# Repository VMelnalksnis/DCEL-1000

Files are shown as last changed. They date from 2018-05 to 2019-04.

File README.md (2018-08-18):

# DCEL-1000

DCEL-1000 is a digital DC electronic load.
* Operates between 0 - 500 VDC, 4 μA<sup>1</sup> - 30A (~200 W maximum, depending on cooling solution)
* Two current ranges: 30 A (2 mA<sup>1</sup> resolution) and 50 mA (4 μA<sup>1</sup> resolution)
* Has dedicated voltage sense terminals
* Consists of two parallel MOSFETs with separate current sense and gate drive
* Controlled via opto-isolated 2.5 MHz SPI interface and control signals
* Requires +12 VDC, provides isolated +5 VDC (1 W)

<sup>1</sup> Theoretical resolution without oversampling assuming 2 LSB noise for current sense ADCs, most likely will change

## Table of contents

1. [About the project](#about-the-project)
1. [Project status](#project-status)
1. [Getting started](#getting-started)
	1. [Dependencies](#dependencies)
1. [License](#license)
1. [Authors](#authors)

# About the project

**[Back to top](#table-of-contents)**

# Project status

Currently working on finishing designing the hardware, both electrical and mechanical.

**[Back to top](#table-of-contents)**

# Getting Started

## Dependencies

* [My EAGLE libraries](https://github.com/VMelnalksnis/Eagle-Libraries)

**[Back to top](#table-of-contents)**

# License

Copyright (c) 2018 Valters Melnalksnis

This project is licensed under the MIT License - see [LICENSE.txt](LICENSE.txt) file for details.

**[Back to top](#table-of-contents)**

# Authors

* **[Valters Melnalksnis](https://github.com/vmelnalksnis)** - *Initial work*

**[Back to top](#table-of-contents)**

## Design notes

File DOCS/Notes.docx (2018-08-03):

The Intel E97378-001 CPU cooler I have has an average thermal resistance of 0.4045 (°C)/W [1] with the fan at maximum speed. Using a K6 Sil-Pad (with a thermal resistance of 0.58 (°C)/W ), at an ambient temperature of 25°C and a maximum junction temperature of 150°C , the maximum power a single MOSFET can dissipate ranges from 107.38W to 113.21W , and 85.9W to 90.57W at maximum junction temperature of 125°C .

Since the power capabilities of a single MOSFET are so low without an expensive cooling solution, the next best choice is to use multiple MOSFETs. When using multiple parallel MOSFETs, especially in linear mode, it is better to keep them at the same temperature to limit the possibility of thermal runaway or other failures due to differences between them. Currently the best way I see of doing that is using a copper busbar for the drain connections of the MOSFETs. This allows the usage of thermal grease, which offers the lowest thermal resistance between the case and heatsink ( <0.4(°C)/W , depending on the source). The busbar would then be mounted to an actively cooled heatsink with an electrically isolating thermal interface, most likely Sil-Pad. Although this increases the total thermal resistance between junction and heatsink, and thus ambient, it allows heat to escape the junction faster, which generally is the limiting factor, more so in pulse operation.

To sum up, use the CPU cooler pressure mounting the MOSFET between it and the PCB using a mounting bracket/backplate. Probably use the IXTK102N65X2, because it has a lowest R_(thJC) among DC SOA rated MOSFETs ( 0.12 (°C)/W versus 0.18(°C)/W on most others), resulting in 5% difference in maximum power using the Intel cooler, and increases with lower total thermal resistance. Furthermore, it has a DC SOA throughout its V_(DS) range of 650V , while the next best is 63V out of 250V . And it only costs 15.68€ . The only real downside is the current limit at low voltages – 20A@1V , 36A@2V .

When calculating maximum power at high currents, power dissipated in the sense resistor, PCB traces and wires should be accounted for; with 50A load on single MOSFET, the sense resistor will dissipate 5W, bypass MOSFETs will dissipate 4.5W, 10AWG wires will dissipate ~5W/m, in total adding about 15W per MOSFET.

- Simulate bypass driver on all 6 MOSFETs
- Figure out input protection
- Redesign the whole physical layout
- Find parts

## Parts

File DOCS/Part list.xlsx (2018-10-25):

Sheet: Used
Resistors
Value | Package | Count | Source | Link | Description | Price per | Total
0.01 | 6332 | 6 |  |  |  |  | €0.00
2 | 3216 | 6 | 610 3-10-2 |  |  |  | €0.00
16 | THT | 1 |  |  | RC snubber |  | €0.00
100 | 1608 | 7 | 610 3-13-3 |  |  |  | €0.00
350 | 1608 | 28 | 610 3-10-5 |  |  |  | €0.00
1000 | 1608 | 4 | 610 3-13-3 |  |  |  | €0.00
2150 | 2012 | 10 | 610 3-9-2 |  |  |  | €0.00
10000 | 1608 | 25 | 610 3-10-5 |  |  |  | €0.00
100000 | 1608 | 4 | 610 3-13-3 |  |  |  | €0.00
2000000 | 3216 | 5 | 610 3-25-2 |  |  |  | €0.00
Capacitors
Value | Package | Count | Source | Link | Description | Price per | Total
1.5e-11 | 1608 | 14 | 610 3-27-4 |  |  |  | €0.00
4.7e-10 | 1608 | 5 | 610 3-13-5 |  |  |  | €0.00
4.7e-10 | THT | 1 |  |  | 5V->5V coupling |  | €0.00
1e-08 | 2012 | 14 | 610 3-17-3 |  |  |  | €0.00
1e-07 | 1608 | 37 |  |  |  |  | €0.00
1.5e-07 | THT | 1 |  |  | RC snubber |  | €0.00
4.7e-07 | 1608 | 5 | 610 3-13-5 |  |  |  | €0.00
4.7e-06 | 3216 | 8 | 610 3-17-5 |  |  |  | €0.00
1e-05 | TANT-C | 2 | 610 3-14-4 |  |  |  | €0.00
4.7e-05 | TANT-D | 1 | 610 3-18-4 |  |  |  | €0.00
0.00022 | THT | 3 |  |  |  |  | €0.00
IC's
Value | Package | Count | Source | Link | Description | Price per | Total
AD420 | SO24W | 2 | 610 3-2-6 |  | 16-bit DAC |  | €0.00
AD620 | SO8 | 5 | 610 3-2-5 |  | Instrumentation amp |  | €0.00
HCPL-063N | SO8 | 7 | 610 3-2-6 |  | Dual opto-coupler |  | €0.00
L7805CV | TO220 | 2 | RTU |  | 5V Linear regulator |  | €0.00
LM50 | SOT23W | 2 | 610 3-14-1 |  | Temperature sensor |  | €0.00
LP2985-3.0 | SOT23-5L | 1 | 610 3-18-1 |  | LDO 3V regulator |  | €0.00
LT1014ISW | SO16W | 2 | RTU |  | Quad opamp |  | €0.00
LTC1865L | SO8 | 4 | 610 3-2-5 |  | 16-bit dual ADC |  | €0.00
MAX743WE | SO16W | 1 | 610 3-2-6 |  | 5V to +/-15V regulator |  | €0.00
Discrete semiconductors
Value | Package | Count | Source | Link | Description | Price per | Total
1N5817-B | DO41-7.6 | 2 | RTU |  |  |  | €0.00
BAS70-04 | SOT23 | 4 | 610 3-12-1 |  |  |  | €0.00
BC807-40 | SOT23 | 16 | 610 3-11-1 |  |  |  | €0.00
BC817-40 | SOT23 | 4 | 610 3-10-1 |  |  |  | €0.00
IXTK102N65X2 | TO264 | 2 | farnell | lv.farnell.com/ixys-semiconductor/ixtk102n65x2/mosfet-n-ch-650v-102a-to-264p/dp/2674784 |  | €12.88 | €25.76
SiRC10DP | SO8 | 4 | RTU |  |  |  | €0.00
Connectors
Value | Package | Count | Source | Link | Description | Price per | Total
Barrel Jack |  | 1 | Me |  |  |  | €0.00
Fan header | 4 pin | 2 |  |  |  |  | €0.00
Header pins |  | 1 | Me |  |  |  | €0.00
Screw terminals | 2/7.62 pitch | 2 | digikey | digikey.lv/product-detail/en/amphenol-anytek/T70243500000G/609-3954-ND/2261340 |  | €0.89 | €1.78
The rest
Value | Package | Count | Source | Link | Description | Price per | Total
100µ inductor |  | 2 | farnell | lv.farnell.com/coilcraft/mss1260-104mld/inductor-pwr-100uh-2-1a-20-8mhz/dp/2288438 |  | €1.22 | €2.44
Heatsink | LGA1155/755 | 2 | Me |  |  |  | €0.00
MOV |  | 4 |  |  |  |  | €0.00
RFMM-0505S | SIP7 | 1 | digikey | digikey.lv/products/en?keywords=RFMM-0505S | 5V->5V isolated supply | €1.45 | €1.45
Thermal interface |  |  |  |  |  |  | €0.00
Total: |  | 260 |  |  |  |  | €31.43

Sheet: Available
ADC |  | DAC |  | OpAmp |  | Vol.reg. |  | Temp. |  | Opto |  | Reference
Part | Location | Part | Location | Part | Location | Part | Location | Part | Location | Part | Location | Part
AD677 | 610-IC | AD420 | 610-IC | AD620 | 610-IC | 79L05 | 610-IC | LM20 | 610-IC | 4N37 | 610-IC | AD1582 | 610-IC
AD9235 | 610-IC | DAC08 | 610-IC | AD707 | 610-IC | LM2573 | 610-IC | LM50 | 610-IC | FOD817A | 610-IC | M109A | 610-IC
LC549 | 610-IC | LTC1453 | 610-IC | AD8065 | 610-IC | LM2671 | 610-IC | LM75A | 610-IC | HCNW2611 | 610-IC | LT1004CZ12 | 524-Mikro
LTC1865 | 610-IC | MAX518 | 610-IC | EL2044CSZ | 610-IC | LM2674 | 610-IC | LM45BIM3 | 524-Mikro | HCPL-061N | 610-IC
PCF8591 | 610-IC | PCF8591 | 610-IC | LF412C | 610-IC | LM317L | 610-IC | LM35D | 524-Mikro | HCPL-063N | 610-IC
DS11307 | 524-Mikro | LTC1663CS5 | 524-Mikro | LM7121 | 610-IC | LM5576 | 610-IC |  |  | PC355 | 610-IC
 |  |  |  | LM837 | 610-IC | LP2985AIM5-3.0 | 610-IC |  |  | SFH6156 | 610-IC
 |  |  |  | LMC660 | 610-IC | LP2985AIM5-3.1 | 610-IC |  |  | IL223AT | 524-Mikro
 |  |  |  | LMC662 | 610-IC | LT1761 | 610-IC
 |  |  |  | LT1014 | 610-IC | LT1964 | 610-IC
 |  |  |  | TL051C | 610-IC | LTC1261 | 610-IC
 |  |  |  | TLC27L4B | 610-IC | MAX743 | 610-IC
 |  |  |  | UA748CDP | 610-DIP | TL317 | 610-IC
 |  |  |  | LM837N | 610-DIP | TPS40055-EP | 610-IC
 |  |  |  | LM358N | 610-DIP | TPS767D301 | 610-IC
 |  |  |  | LF412CN | 610-DIP | XC6209F312MR | 610-IC
 |  |  |  | LF357 | 610-DIP | ICL7660CPA | 610-DIP
 |  |  |  | ICL7612BCPA | 610-DIP | TPS54616 | 524-Mikro
 |  |  |  | GL358 | 610-DIP | S-81250AG | 524-Mikro
 |  |  |  | AMP01FX | 610-DIP | LM79L05ACM | 524-Mikro
 |  |  |  | TS9241 | 524-Mikro | LM2576HVT-ADJ | 524-Mikro
 |  |  |  | TS902ID | 524-Mikro | LM1089CS-ADJ | 524-Mikro
 |  |  |  | TLC274CD | 524-Mikro | LM78M05CS | 524-Mikro
 |  |  |  | TLC271 | 524-Mikro | L4885CV | 524-Mikro
 |  |  |  | TLC074CN | 524-Mikro | 78L05 | 524-Mikro
 |  |  |  | TL084 | 524-Mikro
 |  |  |  | TL082CP | 524-Mikro
 |  |  |  | TL074 | 524-Mikro
 |  |  |  | TL064CD | 524-Mikro
 |  |  |  | TCA0372 | 524-Mikro
 |  |  |  | OPA77FP | 524-Mikro
 |  |  |  | OPA349 | 524-Mikro
 |  |  |  | OPA2137 | 524-Mikro
 |  |  |  | OP77E | 524-Mikro
 |  |  |  | LS204CN | 524-Mikro
 |  |  |  | LMC662AIN | 524-Mikro
 |  |  |  | LM258 | 524-Mikro
 |  |  |  | AD8532AR | 524-Mikro
 |  |  |  | AD811 | 524-Mikro
 |  |  |  | 27L4AC | 524-Mikro
 |  |  |  | 27L2C | 524-Mikro

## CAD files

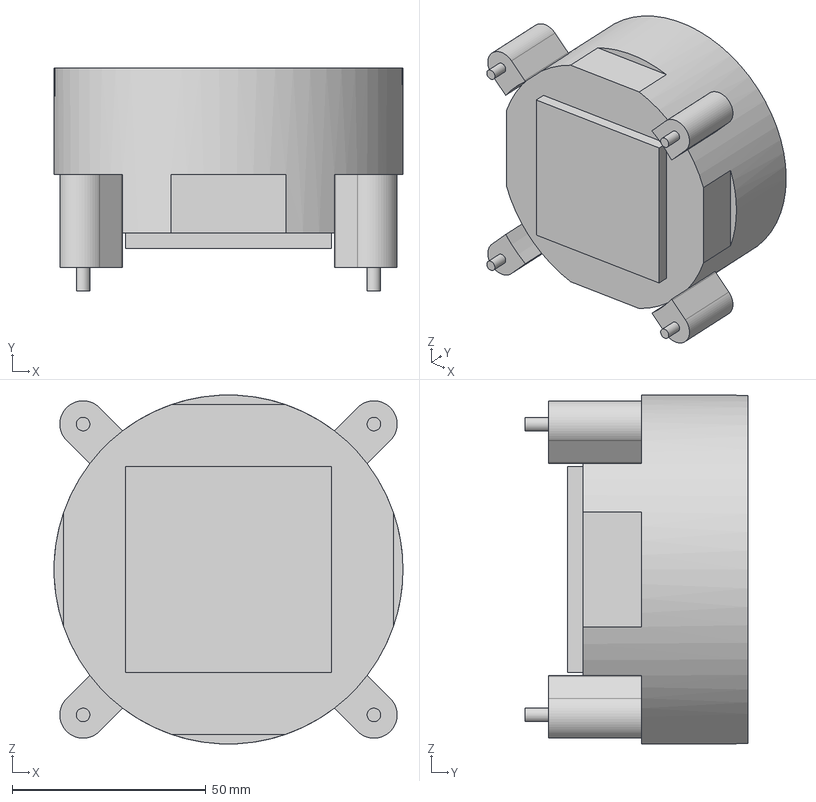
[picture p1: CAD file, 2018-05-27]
MODELS/Intel E97378-00.step
90.0 x 57.5 x 89.9 mm

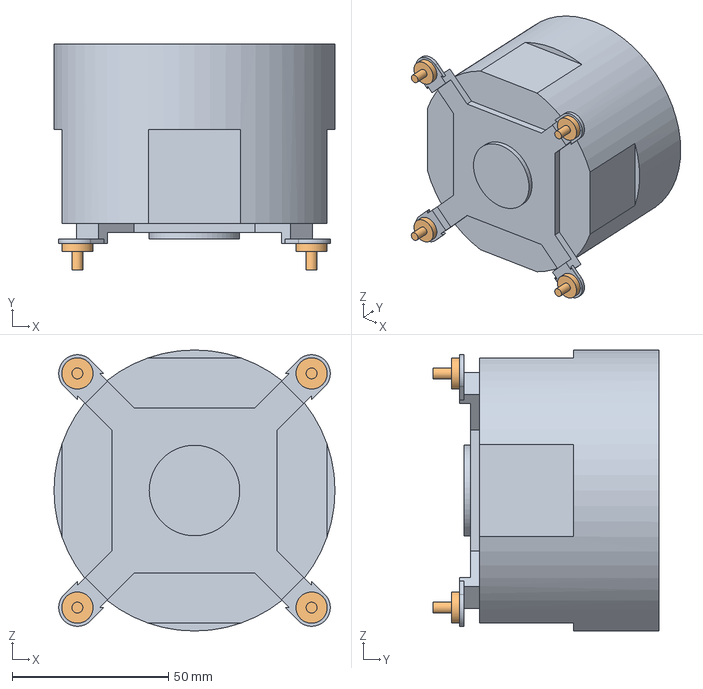
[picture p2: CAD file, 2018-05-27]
MODELS/Intel D95263-001.step
90.0 x 72.5 x 90.0 mm

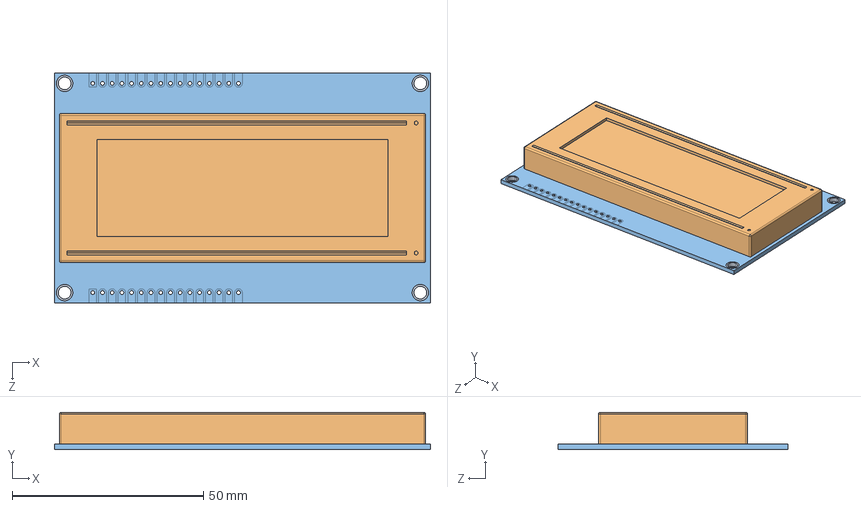
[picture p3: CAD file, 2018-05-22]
MODELS/20X4LCD JHD204A.STEP
98.3 x 9.76 x 60.0 mm

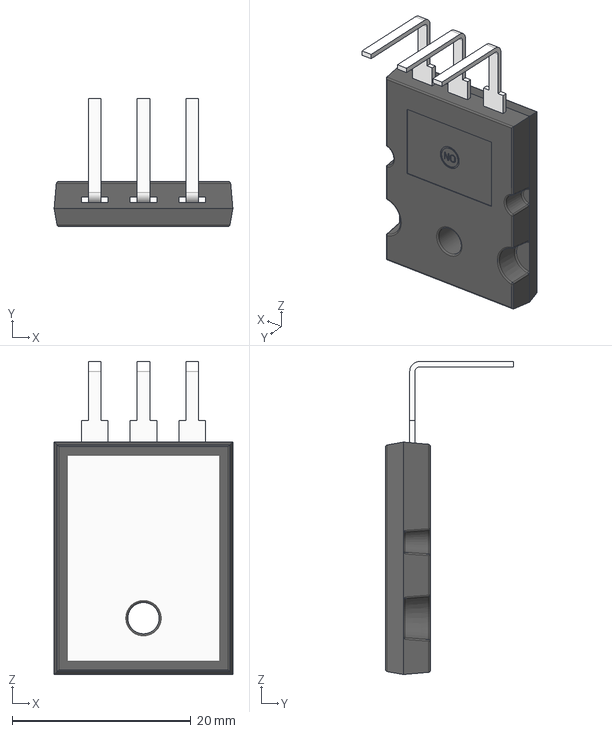
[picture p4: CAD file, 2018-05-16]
MODELS/TO-264-3-HM.stp
20.0 x 14.3 x 35.0 mm

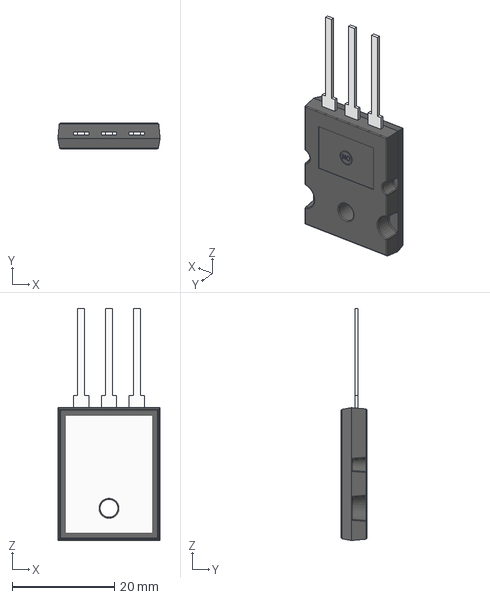
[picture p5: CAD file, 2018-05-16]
MODELS/TO-264-3-VM.stp
20.0 x 5.00 x 45.4 mm

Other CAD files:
MODELS/TO-264-3-HM.ipt
MODELS/TO-264-3-VM.ipt

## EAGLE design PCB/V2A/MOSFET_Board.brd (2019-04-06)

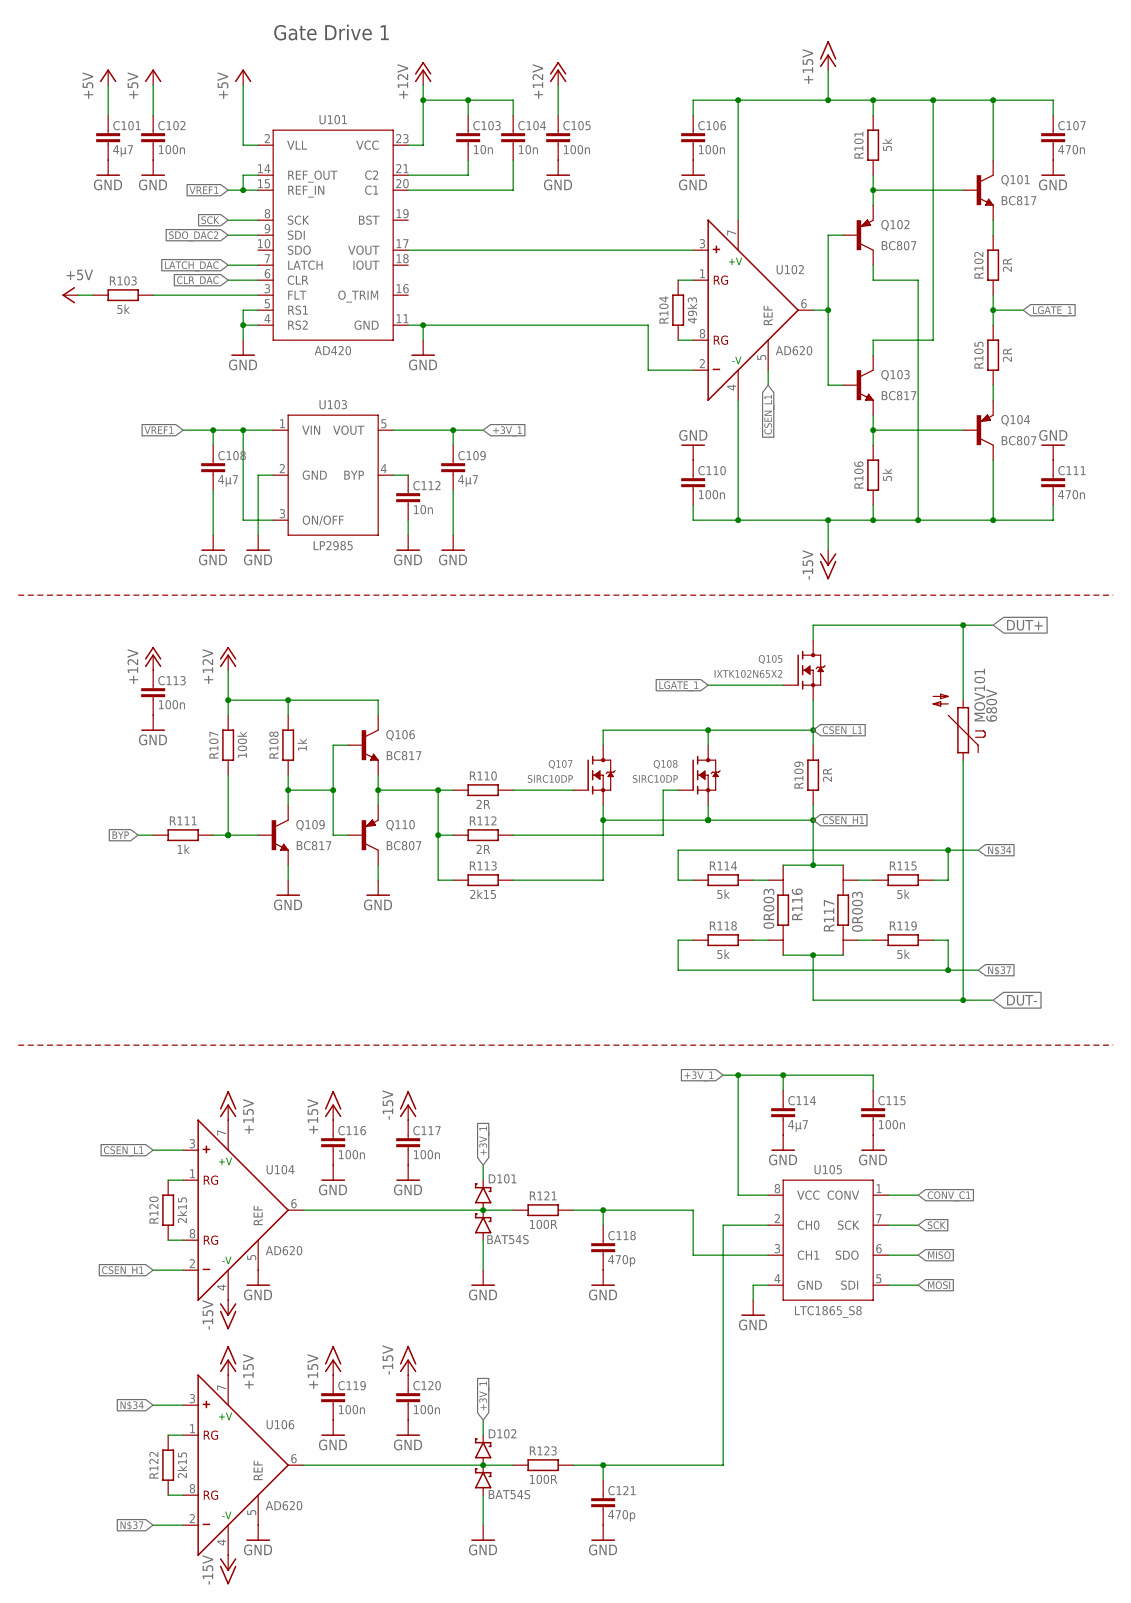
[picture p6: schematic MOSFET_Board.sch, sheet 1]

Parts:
C101, C108, C109, C114: 4µ7; CAPC3216X135
C102, C105, C106, C110, C113, C115, C116, C117, C119, C120: 100n; CAPC1508X45
C103, C104, C112: 10n; CAPC1508X45
C107, C111: 470n; CAPC1508X45
C118, C121: 470p; CAPC1508X45
D101, D102: BAT54S; SOT95P230X110-3
MOV101: 680V; S14K680
Q101, Q103, Q106, Q109: BC817; SOT95P240X110-3
Q102, Q104, Q110: BC807; SOT95P240X110-3
Q105: IXTK102N65X2; TO-264P-V
Q107, Q108: SIRC10DP; POWERPAK-SO-8
R101, R103, R106, R114, R115, R118, R119: 5k; RESC1608X70
R102, R105, R109, R110, R112: 2R; RESC3216X71
R104: 49k3; RESC1608X70
R107: 100k; RESC1608X70
R108, R111: 1k; RESC1608X70
R113, R120, R122: 2k15; RESC2012X65
R116, R117: 0R003; WSL3637_0.01
R121, R123: 100R; RESC1608X70
U101: AD420; SOIC127P1032X265-24
U102, U104, U106: AD620; SOIC127P599X175-8
U103: LP2985; SOT95P280X145-5
U105: LTC1865_S8; SOIC127P599X175-8

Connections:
+3V_1: C109.1, C114.1, C115.1, D101.2 (C2), D102.2 (C2), U103.5 (VOUT), U105.8 (VCC); also elsewhere on the board
+5V: C101.1, C102.1, R103.2, U101.2 (VLL); also elsewhere on the board
+12V: C103.1, C104.1, C105.1, C113.1, Q106.3 (C), R107.2, R108.2, U101.23 (VCC); also elsewhere on the board
+15V: C106.1, C107.1, C116.1, C119.1, Q101.3 (C), Q103.3 (C), R101.2, U102.7 (+V), U104.7 (+V), U106.7 (+V); also elsewhere on the board
-15V: C110.2, C111.2, C117.1, C120.1, Q102.3 (C), Q104.3 (C), R106.1, U102.4 (-V), U104.4 (-V), U106.4 (-V); also elsewhere on the board
BPY1G1: Q107.4 (G), R110.2
BYP: R111.1; also elsewhere on the board
BYP1: Q106.2 (E), Q110.2 (E), R110.1, R112.1, R113.1
BYP1G2: Q108.4 (G), R112.2
CLR_DAC: U101.6 (CLR); also elsewhere on the board
CONV_C1: U105.1 (CONV); also elsewhere on the board
CSEN_H1: Q107.1 (S), Q107.2 (S), Q107.3 (S), Q108.1 (S), Q108.2 (S), Q108.3 (S), R109.1, R113.2, R116.I1, R117.I2, U104.2 (-)
CSEN_L1: Q105.3 (S), Q107.5 (D), Q107.6 (D), Q107.7 (D), Q107.8 (D), Q108.5 (D), Q108.6 (D), Q108.7 (D), Q108.8 (D), R109.2, U102.5 (REF), U104.3 (+)
DUT+: MOV101.2, Q105.2 (D); also elsewhere on the board
DUT-: MOV101.1, R116.I2, R117.I1; also elsewhere on the board
GND: C101.2, C102.2, C105.2, C106.2, C107.2, C108.2, C109.2, C110.1, C111.1, C112.2, C113.2, C114.2, C115.2, C116.2, C117.2, C118.2, C119.2, C120.2, C121.2, D101.1 (A1), D102.1 (A1), Q109.2 (E), Q110.3 (C), U101.4 (RS2), U101.5 (RS1), U101.11 (GND), U102.2 (-), U103.2 (GND), U104.5 (REF), U105.4 (GND), U106.5 (REF); also elsewhere on the board
HIGHC1: C121.1, R123.2, U105.2 (CH0)
LATCH_DAC: U101.7 (LATCH); also elsewhere on the board
LGATE_1: Q105.1 (G), R102.1, R105.2
LOWC1: C118.1, R121.2, U105.3 (CH1)
MISO: U105.6 (SDO); also elsewhere on the board
MOSI: U105.5 (SDI); also elsewhere on the board
unnamed: Q101.1 (B), Q102.2 (E), R101.1
unnamed: R104.2, U102.1 (RG)
unnamed: C103.2, U101.21 (C2)
unnamed: C104.2, U101.20 (C1)
unnamed: Q106.1 (B), Q109.3 (C), Q110.1 (B), R108.1
unnamed: R104.1, U102.8 (RG)
unnamed: D102.3 (C1A2), R123.1, U106.6 (OUT)
unnamed: Q109.1 (B), R107.1, R111.2
unnamed: U101.17 (VOUT), U102.3 (+)
unnamed: C112.1, U103.4 (BYP)
unnamed: Q104.2 (E), R105.1
unnamed: Q101.2 (E), R102.2
unnamed: D101.3 (C1A2), R121.1, U104.6 (OUT)
unnamed: R115.2, R117.E2
unnamed: R114.1, R115.1, U106.3 (+)
unnamed: R116.E2, R118.1
unnamed: R118.2, R119.2, U106.2 (-)
unnamed: R117.E1, R119.1
unnamed: R114.2, R116.E1
unnamed: R103.1, U101.3 (FLT)
unnamed: Q102.1 (B), Q103.1 (B), U102.6 (OUT)
unnamed: Q103.2 (E), Q104.1 (B), R106.2
RG1_L3: R122.2, U106.1 (RG)
RG1_L4: R120.2, U104.1 (RG)
RG2_L3: R122.1, U106.8 (RG)
RG2_L4: R120.1, U104.8 (RG)
SCK: U101.8 (SCK), U105.7 (SCK); also elsewhere on the board
SDO_DAC2: U101.9 (SDI); also elsewhere on the board
VREF1: C108.1, U101.14 (REF_OUT), U101.15 (REF_IN), U103.1 (VIN), U103.3 (ON/OFF)

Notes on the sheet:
Gate Drive 1

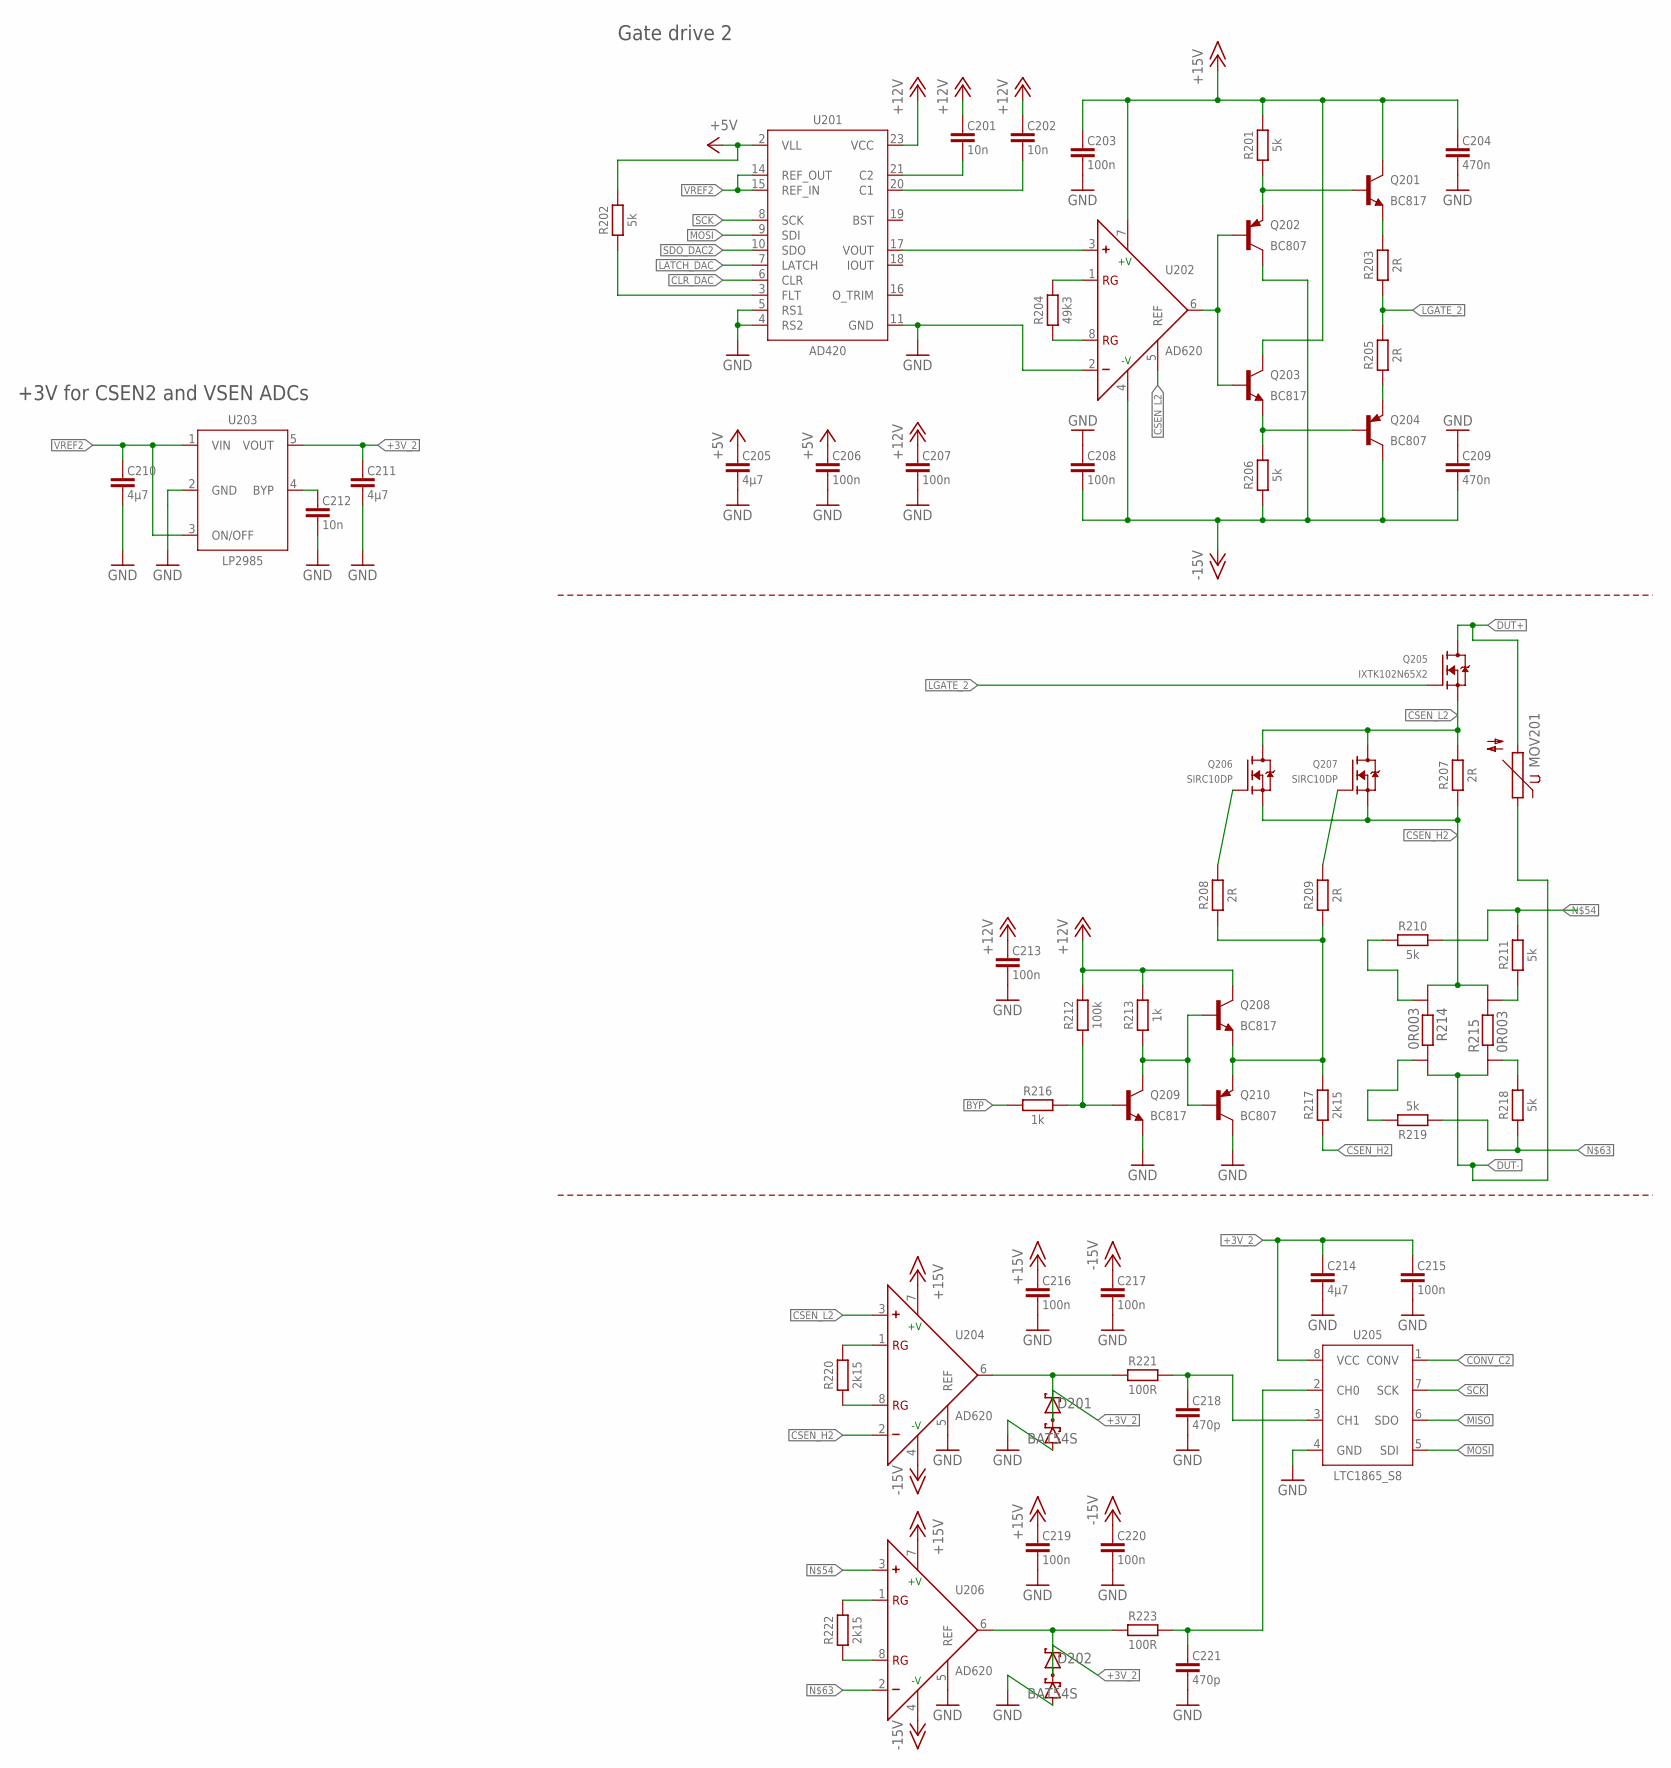
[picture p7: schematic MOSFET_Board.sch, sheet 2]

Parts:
C201, C202, C212: 10n; CAPC1508X45
C203, C206, C207, C208, C213, C215, C216, C217, C219, C220: 100n; CAPC1508X45
C204, C209: 470n; CAPC1508X45
C205, C210, C211, C214: 4µ7; CAPC3216X135
C218, C221: 470p; CAPC1508X45
D201, D202: BAT54S; SOT95P230X110-3
MOV201: MOV-14X7.4; S14K680
Q201, Q203, Q208, Q209: BC817; SOT95P240X110-3
Q202, Q204, Q210: BC807; SOT95P240X110-3
Q205: IXTK102N65X2; TO-264P-V
Q206, Q207: SIRC10DP; POWERPAK-SO-8
R201, R202, R206, R210, R211, R218, R219: 5k; RESC1608X70
R203, R205, R207, R208, R209: 2R; RESC3216X71
R204: 49k3; RESC1608X70
R212: 100k; RESC1608X70
R213, R216: 1k; RESC1608X70
R214, R215: 0R003; WSL3637_0.01
R217, R220, R222: 2k15; RESC2012X65
R221, R223: 100R; RESC1608X70
U201: AD420; SOIC127P1032X265-24
U202, U204, U206: AD620; SOIC127P599X175-8
U203: LP2985; SOT95P280X145-5
U205: LTC1865_S8; SOIC127P599X175-8

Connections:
+3V_2: C211.1, C214.1, C215.1, D201.2 (C2), D202.2 (C2), U203.5 (VOUT), U205.8 (VCC)
+5V: C205.1, C206.1, R202.2, U201.2 (VLL); also elsewhere on the board
+12V: C201.1, C202.1, C207.1, C213.1, Q208.3 (C), R212.2, R213.2, U201.23 (VCC); also elsewhere on the board
+15V: C203.1, C204.1, C216.1, C219.1, Q201.3 (C), Q203.3 (C), R201.2, U202.7 (+V), U204.7 (+V), U206.7 (+V); also elsewhere on the board
-15V: C208.2, C209.2, C217.1, C220.1, Q202.3 (C), Q204.3 (C), R206.1, U202.4 (-V), U204.4 (-V), U206.4 (-V); also elsewhere on the board
BYP: R216.1; also elsewhere on the board
BYP2: Q208.2 (E), Q210.2 (E), R208.1, R209.1, R217.2
BYP2G1: Q206.4 (G), R208.2
BYP2G2: Q207.4 (G), R209.2
CLR_DAC: U201.6 (CLR); also elsewhere on the board
CONV_C2: U205.1 (CONV); also elsewhere on the board
CSEN_H2: Q206.1 (S), Q206.2 (S), Q206.3 (S), Q207.1 (S), Q207.2 (S), Q207.3 (S), R207.1, R214.I1, R215.I2, R217.1, U204.2 (-)
CSEN_L2: Q205.3 (S), Q206.5 (D), Q206.6 (D), Q206.7 (D), Q206.8 (D), Q207.5 (D), Q207.6 (D), Q207.7 (D), Q207.8 (D), R207.2, U202.5 (REF), U204.3 (+)
DUT+: MOV201.2, Q205.2 (D); also elsewhere on the board
DUT-: MOV201.1, R214.I2, R215.I1; also elsewhere on the board
GND: C203.2, C204.2, C205.2, C206.2, C207.2, C208.1, C209.1, C210.2, C211.2, C212.2, C213.2, C214.2, C215.2, C216.2, C217.2, C218.2, C219.2, C220.2, C221.2, D201.1 (A1), D202.1 (A1), Q209.2 (E), Q210.3 (C), U201.4 (RS2), U201.5 (RS1), U201.11 (GND), U202.2 (-), U203.2 (GND), U204.5 (REF), U205.4 (GND), U206.5 (REF); also elsewhere on the board
HIGHC2: C221.1, R223.2, U205.2 (CH0)
LATCH_DAC: U201.7 (LATCH); also elsewhere on the board
LGATE_2: Q205.1 (G), R203.1, R205.2
LOWC2: C218.1, R221.2, U205.3 (CH1)
MISO: U205.6 (SDO); also elsewhere on the board
MOSI: U201.9 (SDI), U205.5 (SDI); also elsewhere on the board
unnamed: Q201.1 (B), Q202.2 (E), R201.1
unnamed: Q204.2 (E), R205.1
unnamed: Q201.2 (E), R203.2
unnamed: Q208.1 (B), Q209.3 (C), Q210.1 (B), R213.1
unnamed: Q209.1 (B), R212.1, R216.2
unnamed: R210.1, R214.E1
unnamed: C201.2, U201.21 (C2)
unnamed: C202.2, U201.20 (C1)
unnamed: Q202.1 (B), Q203.1 (B), U202.6 (OUT)
unnamed: Q203.2 (E), Q204.1 (B), R206.2
unnamed: R202.1, U201.3 (FLT)
unnamed: R211.1, R215.E2
unnamed: R204.2, U202.1 (RG)
unnamed: R204.1, U202.8 (RG)
unnamed: U201.17 (VOUT), U202.3 (+)
unnamed: R215.E1, R218.2
unnamed: R214.E2, R219.2
unnamed: R210.2, R211.2, U206.3 (+)
unnamed: D202.3 (C1A2), R223.1, U206.6 (OUT)
unnamed: D201.3 (C1A2), R221.1, U204.6 (OUT)
unnamed: C212.1, U203.4 (BYP)
unnamed: R218.1, R219.1, U206.2 (-)
RG1_L1: R222.2, U206.1 (RG)
RG1_L2: R220.2, U204.1 (RG)
RG2_L1: R222.1, U206.8 (RG)
RG2_L2: R220.1, U204.8 (RG)
SCK: U201.8 (SCK), U205.7 (SCK); also elsewhere on the board
SDO_DAC2: U201.10 (SDO); also elsewhere on the board
VREF2: C210.1, U201.14 (REF_OUT), U201.15 (REF_IN), U203.1 (VIN), U203.3 (ON/OFF)

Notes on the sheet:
Gate drive 2
+3V for CSEN2 and VSEN ADCs

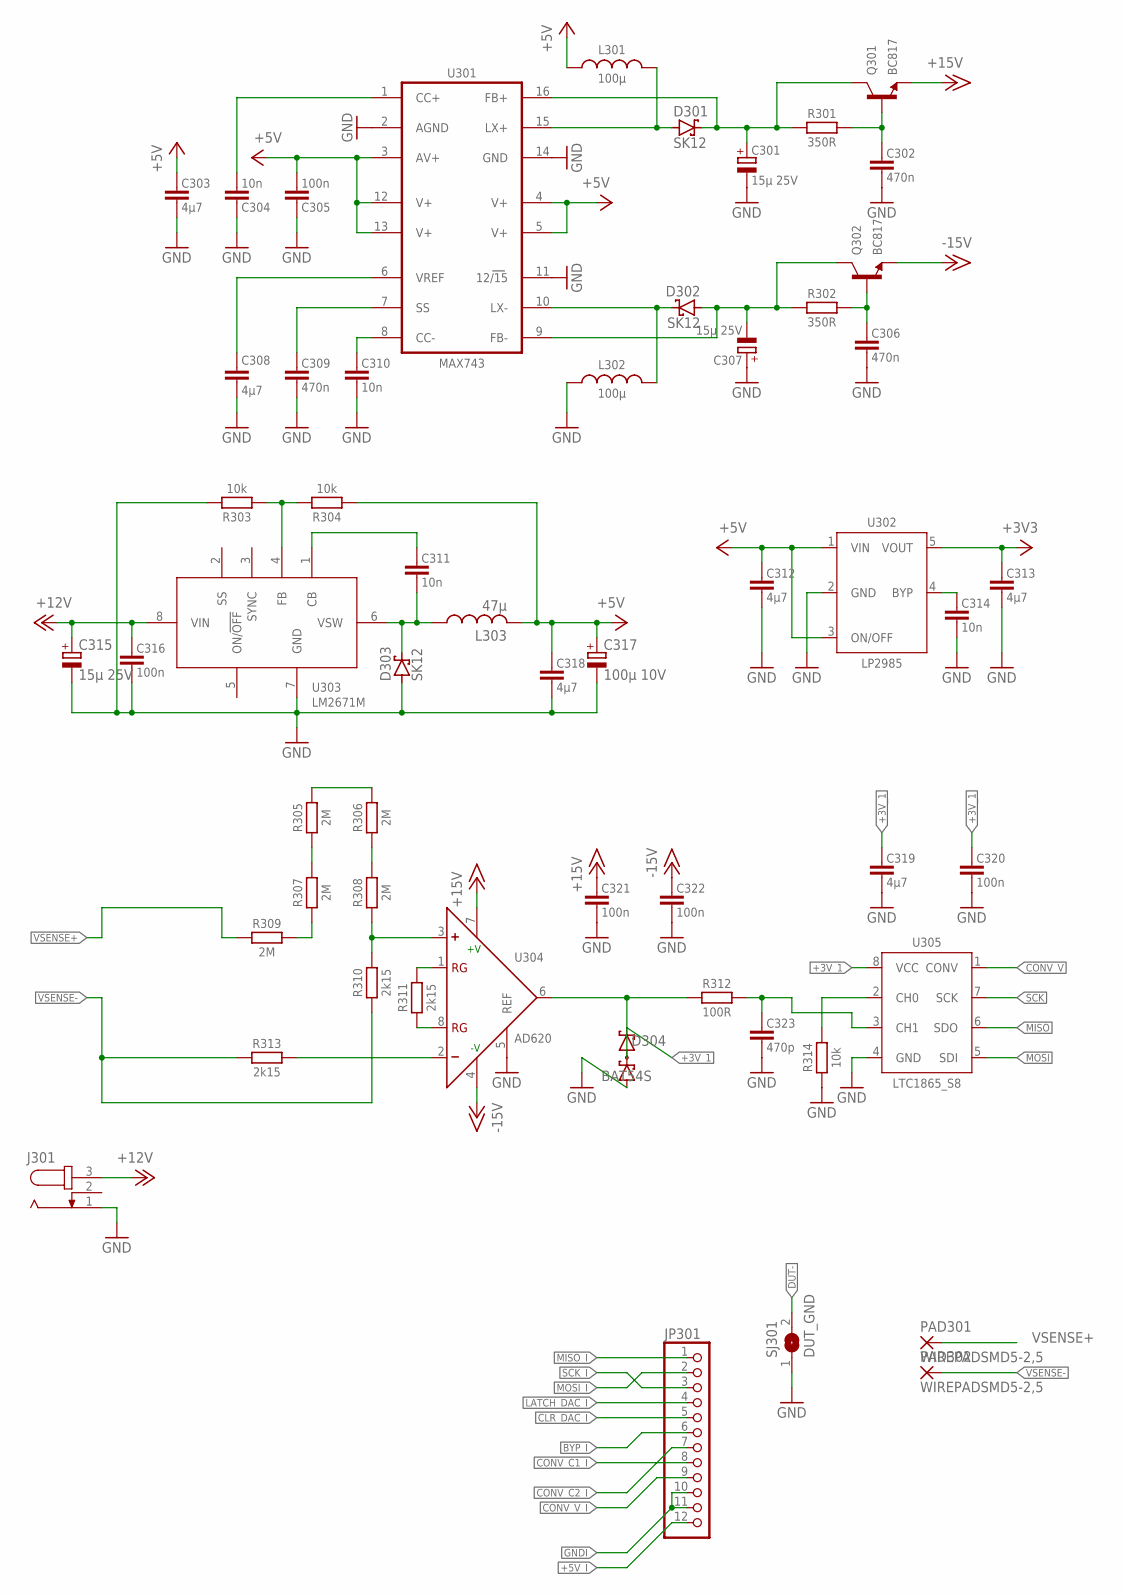
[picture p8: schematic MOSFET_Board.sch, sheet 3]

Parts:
C301, C307, C315: 15µ 25V; CAPCP7343X310
C302, C306, C309: 470n; CAPC1508X45
C303, C308, C312, C313, C318, C319: 4µ7; CAPC3216X135
C304, C310, C311, C314: 10n; CAPC1508X45
C305, C316, C320, C321, C322: 100n; CAPC1508X45
C317: 100µ 10V; CAPCP7343X310
C323: 470p; CAPC1508X45
D301, D302, D303: SK12; DIOM4336X262
D304: BAT54S; SOT95P230X110-3
J301: JACK-PLUG-2.5; SPC4078
JP301: PINHD-1X12; 1X12
L301, L302: 100µ; SRN5040
L303: 47µ; SRN5040
PAD301, PAD302: WIREPADSMD5-2,5; 5-2,5
Q301, Q302: BC817; SOT95P240X110-3
R301, R302: 350R; RESC1608X70
R303, R304, R314: 10k; RESC1608X70
R305, R306, R307, R308, R309: 2M; RESC3216X71
R310, R311, R313: 2k15; RESC2012X65
R312: 100R; RESC1608X70
SJ301: DUT_GND; SJW
U301: MAX743; SOIC127P1032X265-16
U302: LP2985; SOT95P280X145-5
U303: LM2671M; SOIC127P599X175-8
U304: AD620; SOIC127P599X175-8
U305: LTC1865_S8; SOIC127P599X175-8

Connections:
+3V3: C313.1, U302.5 (VOUT); also elsewhere on the board
+3V_1: C319.1, C320.1, D304.2 (C2), U305.8 (VCC); also elsewhere on the board
+5V: C303.1, C305.2, C312.1, C317.1 (+), C318.1, L301.1, L303.2, R304.1, U301.3 (AV+), U301.4 (V+), U301.5 (V+), U301.12 (V+), U301.13 (V+), U302.1 (VIN), U302.3 (ON/OFF); also elsewhere on the board
+5V_I: JP301.12; also elsewhere on the board
+12V: C315.1 (+), C316.1, J301.3, U303.8 (VIN); also elsewhere on the board
+15V: C321.1, Q301.2 (E), U304.7 (+V); also elsewhere on the board
-15V: C322.1, Q302.2 (E), U304.4 (-V); also elsewhere on the board
BYP_I: JP301.6; also elsewhere on the board
CLR_DAC_I: JP301.5; also elsewhere on the board
CONV_C1_I: JP301.8; also elsewhere on the board
CONV_C2_I: JP301.7; also elsewhere on the board
CONV_V: U305.1 (CONV); also elsewhere on the board
CONV_V_I: JP301.9; also elsewhere on the board
DUT-: SJ301.2; also elsewhere on the board
GND: C301.2 (-), C302.2, C303.2, C304.1, C305.1, C306.2, C307.1 (+), C308.2, C309.2, C310.2, C312.2, C313.2, C314.2, C315.2 (-), C316.2, C317.2 (-), C318.2, C319.2, C320.2, C321.2, C322.2, C323.2, D303.2 (A), D304.1 (A1), J301.1, L302.2, R303.2, R314.1, SJ301.1, U301.2 (AGND), U301.11 (12/15), U301.14 (GND), U302.2 (GND), U303.7 (GND), U304.5 (REF), U305.4 (GND); also elsewhere on the board
GNDI: JP301.10, JP301.11; also elsewhere on the board
LATCH_DAC_I: JP301.4; also elsewhere on the board
MISO: U305.6 (SDO); also elsewhere on the board
MISO_I: JP301.1; also elsewhere on the board
MOSI: U305.5 (SDI); also elsewhere on the board
MOSI_I: JP301.2; also elsewhere on the board
unnamed: C311.1, U303.1 (CB)
unnamed: C311.2, D303.1 (C), L303.1, U303.6 (VSW)
unnamed: R303.1, R304.2, U303.4 (FB)
unnamed: D304.3 (C1A2), R312.1, U304.6 (OUT)
unnamed: R306.1, R308.2
unnamed: R305.2, R306.2
unnamed: R305.1, R307.2
unnamed: R314.2, U305.2 (CH0)
unnamed: R308.1, R310.2, U304.3 (+)
unnamed: C323.1, R312.2, U305.3 (CH1)
unnamed: R307.1, R309.2
unnamed: R313.2, U304.2 (-)
unnamed: C310.1, U301.8 (CC-)
unnamed: C309.1, U301.7 (SS)
unnamed: C304.2, U301.1 (CC+)
unnamed: D301.2 (A), L301.2, U301.15 (LX+)
unnamed: C314.1, U302.4 (BYP)
unnamed: D302.1 (C), L302.1, U301.10 (LX-)
unnamed: C301.1 (+), D301.1 (C), Q301.3 (C), R301.1, U301.16 (FB+)
unnamed: C302.1, Q301.1 (B), R301.2
unnamed: C307.2 (-), D302.2 (A), Q302.3 (C), R302.1, U301.9 (FB-)
unnamed: C306.1, Q302.1 (B), R302.2
RG1_H6: R311.2, U304.1 (RG)
RG2_H6: R311.1, U304.8 (RG)
SCK: U305.7 (SCK); also elsewhere on the board
SCK_I: JP301.3; also elsewhere on the board
VREF_MAX743: C308.1, U301.6 (VREF)
VSENSE+: PAD301.1, R309.1
VSENSE-: PAD302.1, R310.1, R313.1

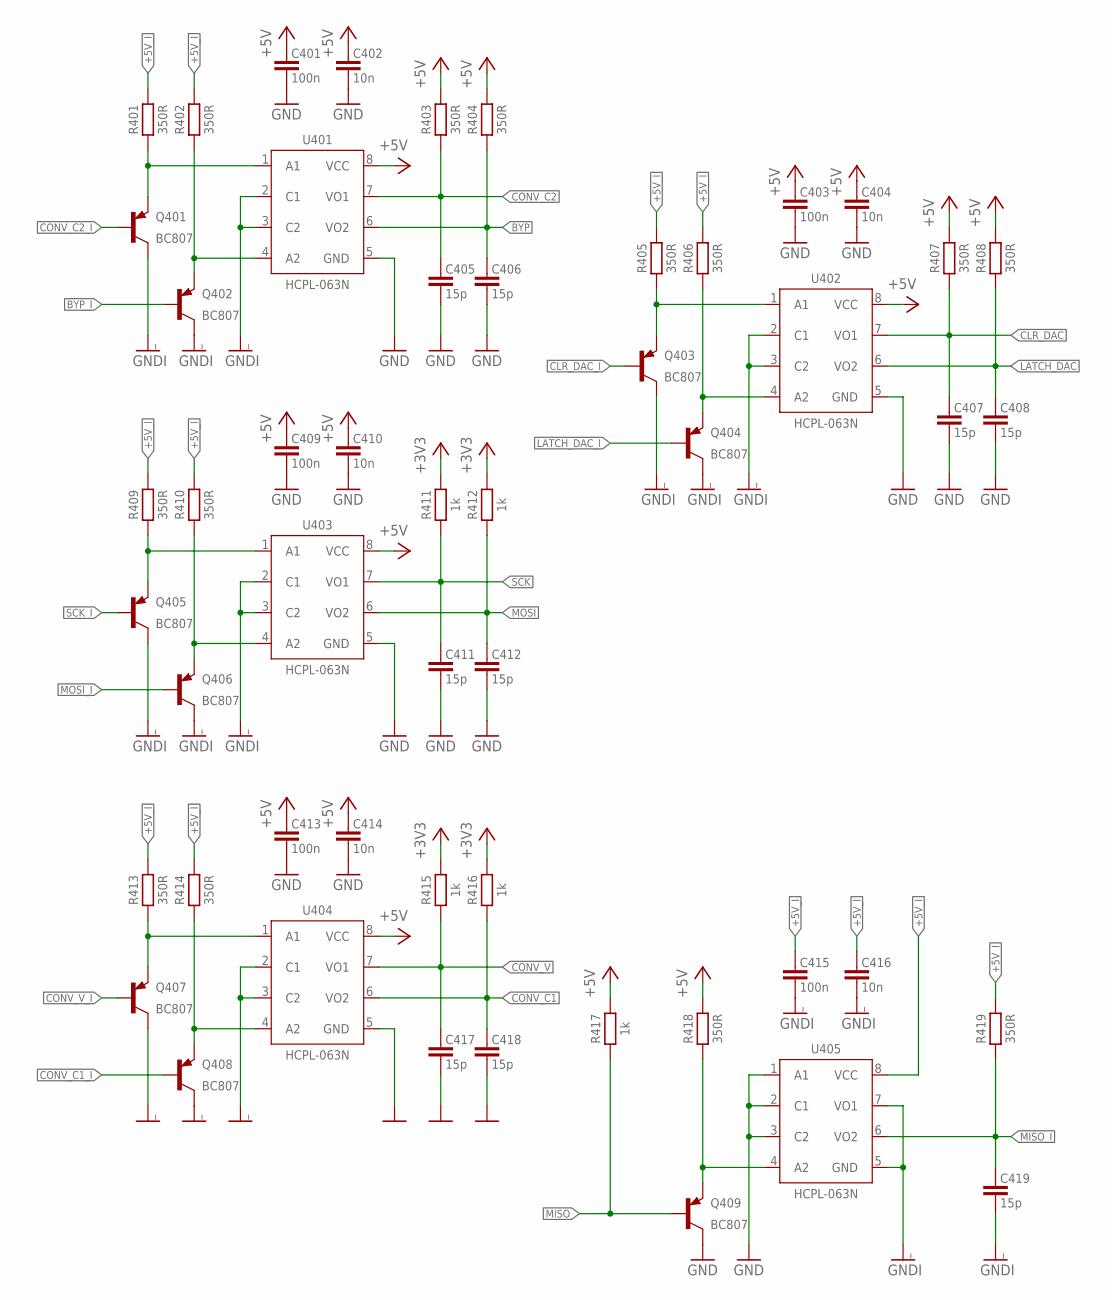
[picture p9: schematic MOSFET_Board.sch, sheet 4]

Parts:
C401, C403, C409, C413, C415: 100n; CAPC1508X45
C402, C404, C410, C414, C416: 10n; CAPC1508X45
C405, C406, C407, C408, C411, C412, C417, C418, C419: 15p; CAPC1508X45
Q401, Q402, Q403, Q404, Q405, Q406, Q407, Q408, Q409: BC807; SOT95P240X110-3
R401, R402, R403, R404, R405, R406, R407, R408, R409, R410, R413, R414, R418, R419: 350R; RESC1608X70
R411, R412, R415, R416, R417: 1k; RESC1608X70
U401, U402, U403, U404, U405: HCPL-063N; SOIC127P599X175-8

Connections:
+3V3: R411.2, R412.2, R415.2, R416.2; also elsewhere on the board
+5V: C401.1, C402.1, C403.1, C404.1, C409.1, C410.1, C413.1, C414.1, R403.2, R404.2, R407.2, R408.2, R417.2, R418.2, U401.8 (VCC), U402.8 (VCC), U403.8 (VCC), U404.8 (VCC); also elsewhere on the board
+5V_I: C415.1, C416.1, R401.2, R402.2, R405.2, R406.2, R409.2, R410.2, R413.2, R414.2, R419.2, U405.8 (VCC); also elsewhere on the board
BYP: C406.1, R404.1, U401.6 (VO2); also elsewhere on the board
BYP_I: Q402.1 (B); also elsewhere on the board
CLR_DAC: C407.1, R407.1, U402.7 (VO1); also elsewhere on the board
CLR_DAC_I: Q403.1 (B); also elsewhere on the board
CONV_C1: C418.1, R416.1, U404.6 (VO2); also elsewhere on the board
CONV_C1_I: Q408.1 (B); also elsewhere on the board
CONV_C2: C405.1, R403.1, U401.7 (VO1); also elsewhere on the board
CONV_C2_I: Q401.1 (B); also elsewhere on the board
CONV_V: C417.1, R415.1, U404.7 (VO1); also elsewhere on the board
CONV_V_I: Q407.1 (B); also elsewhere on the board
GND: C401.2, C402.2, C403.2, C404.2, C405.2, C406.2, C407.2, C408.2, C409.2, C410.2, C411.2, C412.2, C413.2, C414.2, C417.2, C418.2, Q409.3 (C), U401.5 (GND), U402.5 (GND), U403.5 (GND), U404.5 (GND), U405.1 (A1), U405.2 (C1), U405.3 (C2); also elsewhere on the board
GNDI: C415.2, C416.2, C419.2, Q401.3 (C), Q402.3 (C), Q403.3 (C), Q404.3 (C), Q405.3 (C), Q406.3 (C), Q407.3 (C), Q408.3 (C), U401.2 (C1), U401.3 (C2), U402.2 (C1), U402.3 (C2), U403.2 (C1), U403.3 (C2), U404.2 (C1), U404.3 (C2), U405.5 (GND), U405.7 (VO1); also elsewhere on the board
LATCH_DAC: C408.1, R408.1, U402.6 (VO2); also elsewhere on the board
LATCH_DAC_I: Q404.1 (B); also elsewhere on the board
MISO: Q409.1 (B), R417.1; also elsewhere on the board
MISO_I: C419.1, R419.1, U405.6 (VO2); also elsewhere on the board
MOSI: C412.1, R412.1, U403.6 (VO2); also elsewhere on the board
MOSI_I: Q406.1 (B); also elsewhere on the board
unnamed: Q409.2 (E), R418.1, U405.4 (A2)
unnamed: Q405.2 (E), R409.1, U403.1 (A1)
unnamed: Q406.2 (E), R410.1, U403.4 (A2)
unnamed: Q401.2 (E), R401.1, U401.1 (A1)
unnamed: Q402.2 (E), R402.1, U401.4 (A2)
unnamed: Q403.2 (E), R405.1, U402.1 (A1)
unnamed: Q404.2 (E), R406.1, U402.4 (A2)
unnamed: Q407.2 (E), R413.1, U404.1 (A1)
unnamed: Q408.2 (E), R414.1, U404.4 (A2)
SCK: C411.1, R411.1, U403.7 (VO1); also elsewhere on the board
SCK_I: Q405.1 (B); also elsewhere on the board

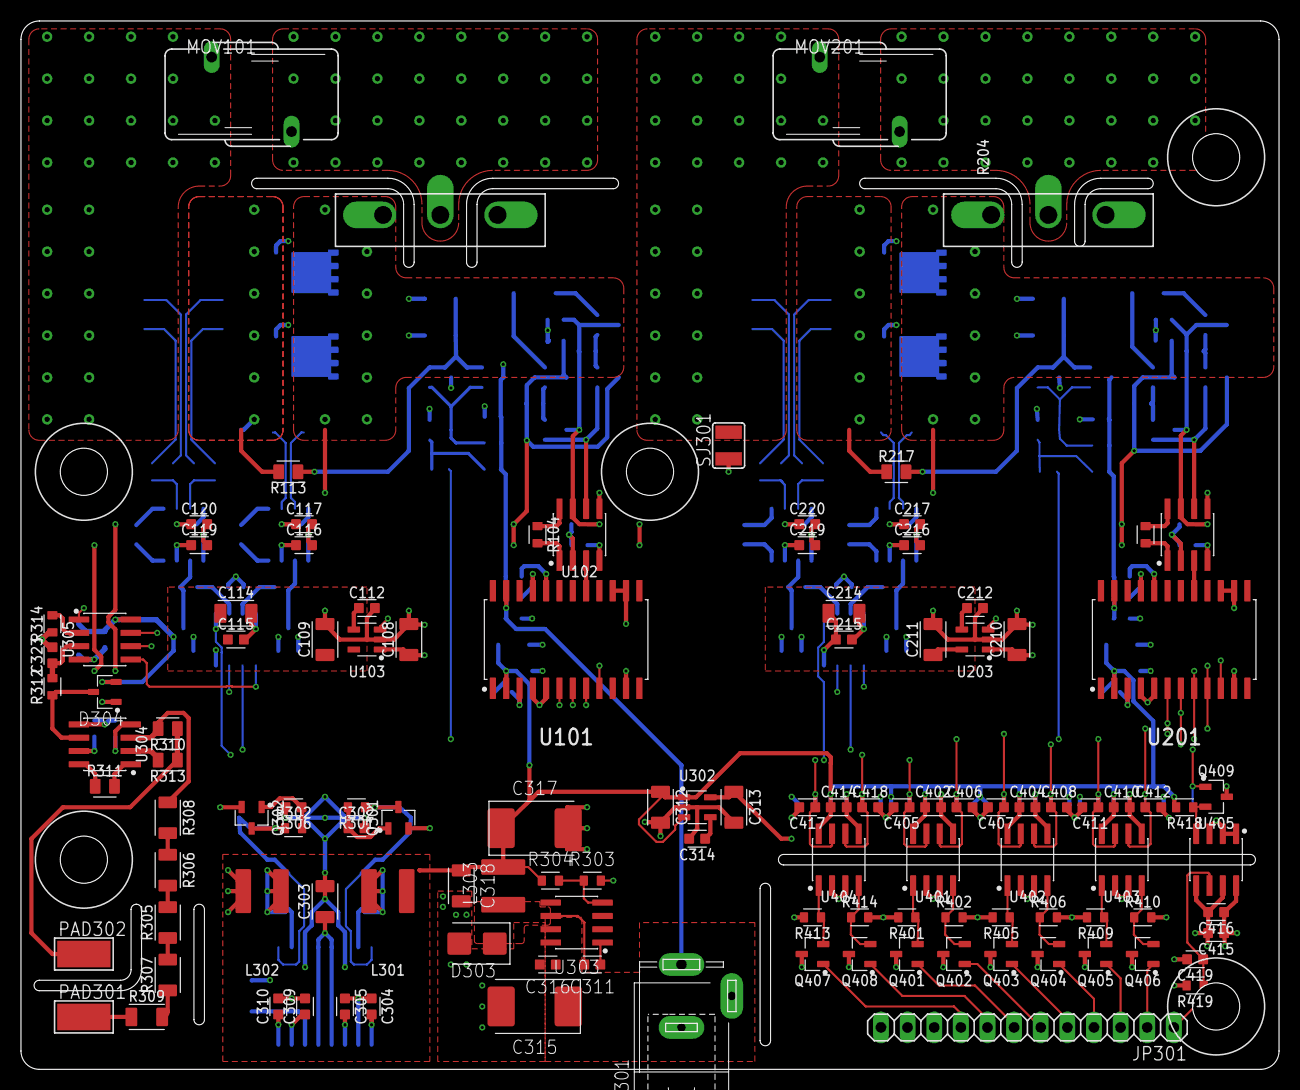
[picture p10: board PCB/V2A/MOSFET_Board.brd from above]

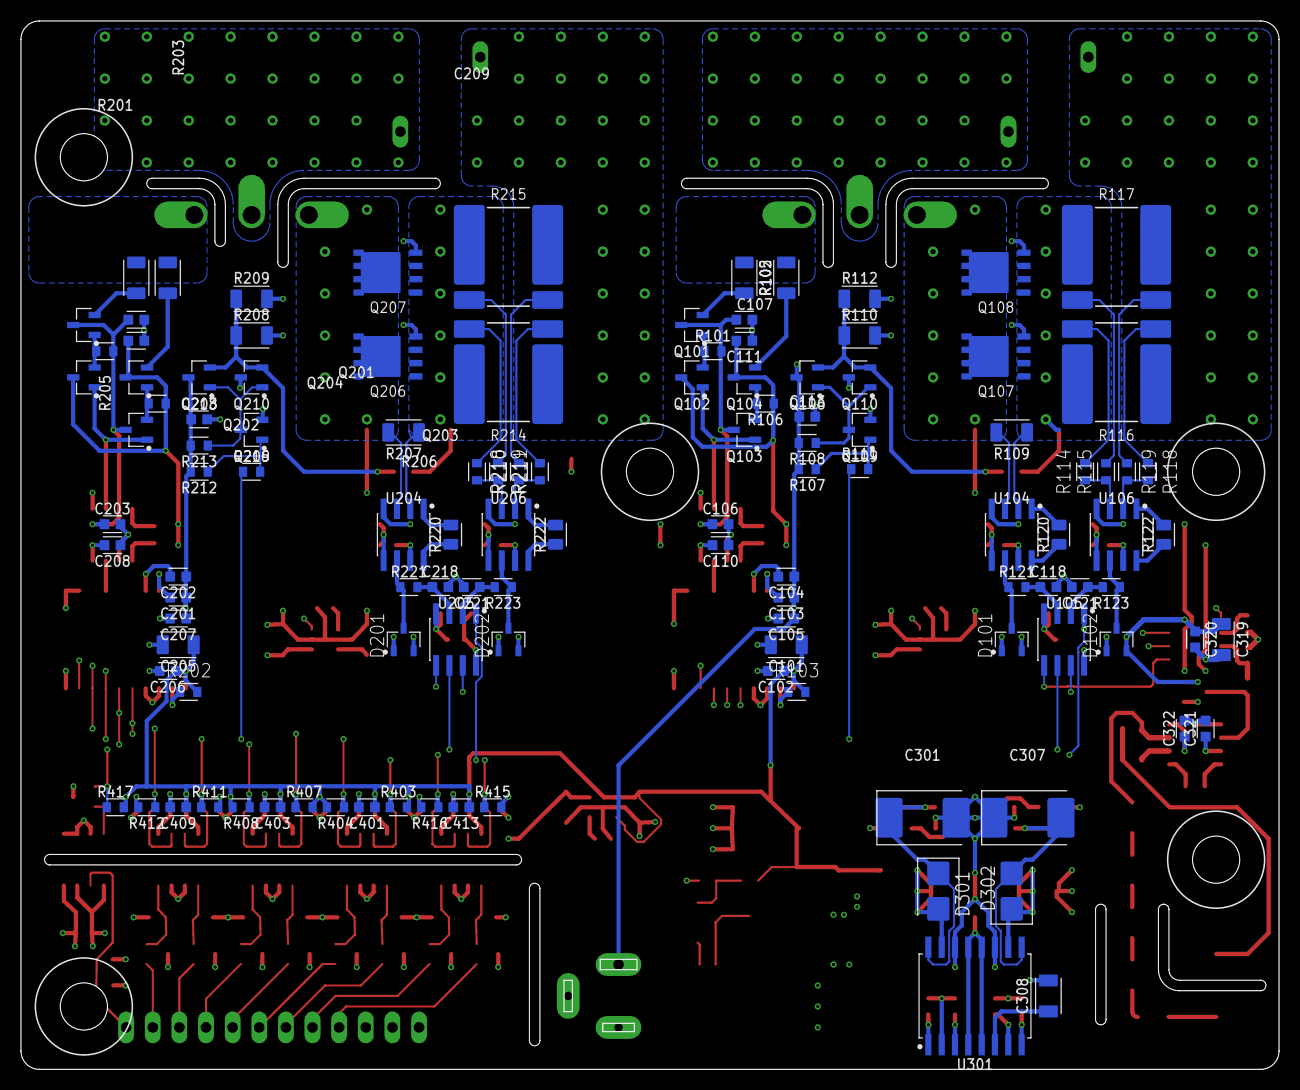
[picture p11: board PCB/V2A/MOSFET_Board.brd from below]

Board: 4 copper layers, 120.0 x 100.0 mm, 239 parts (117 on the bottom side), 137 nets.

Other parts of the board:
U$1, U$2, U$3, U$4, U$5: M4

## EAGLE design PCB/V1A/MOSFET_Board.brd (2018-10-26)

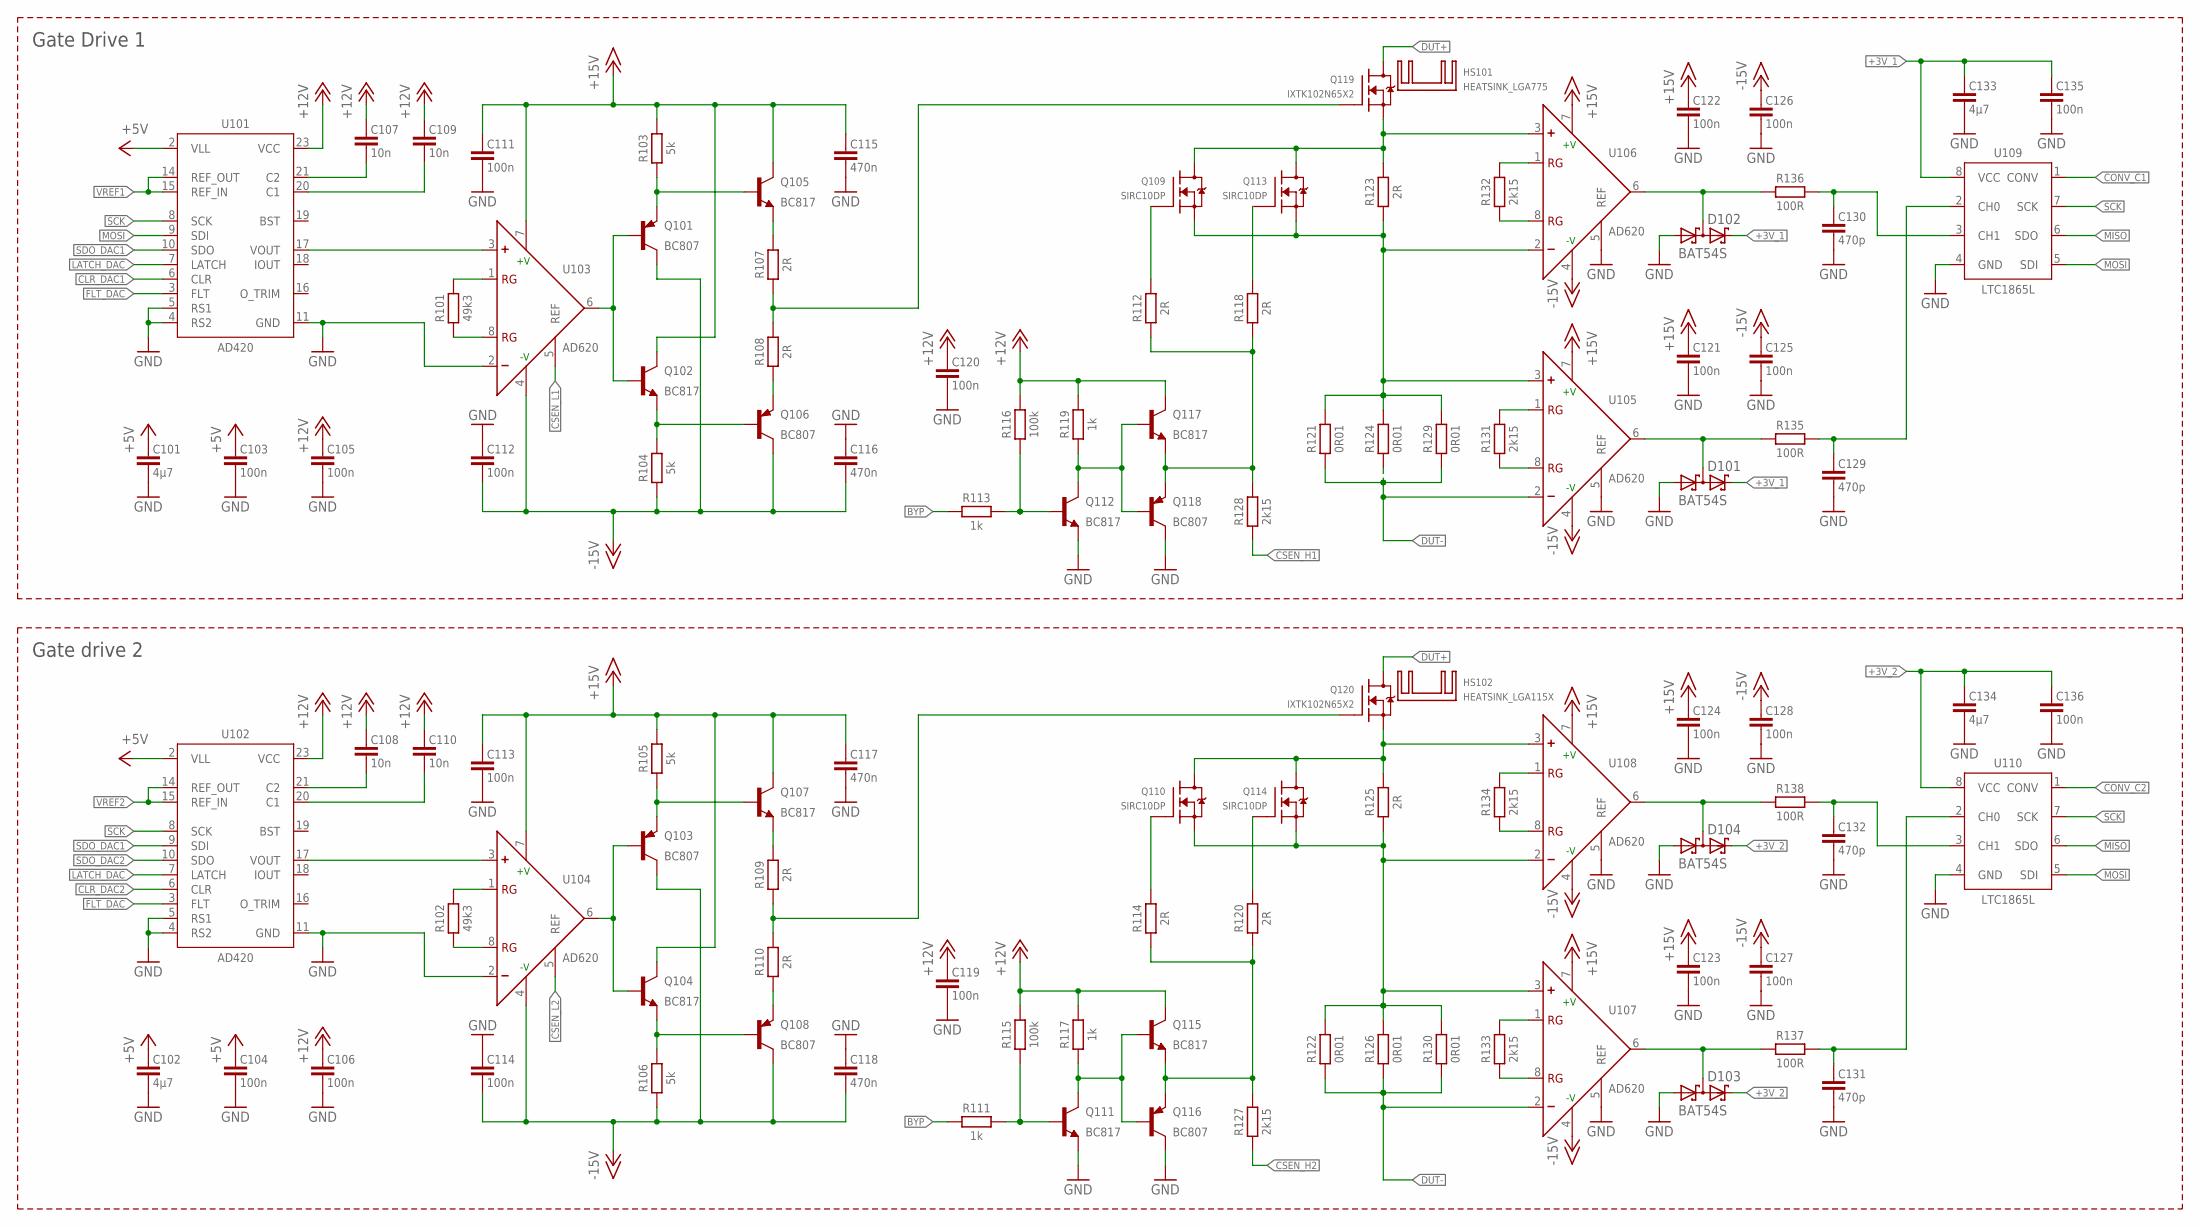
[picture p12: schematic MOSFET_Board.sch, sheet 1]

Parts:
C101, C102, C133, C134: 4µ7; CAPC3216
C103, C104, C105, C106, C111, C112, C113, C114, C119, C120, C121, C122, C123, C124, C125, C126, C127, C128, C135, C136: 100n; CAPC1608
C107, C108, C109, C110: 10n; CAPC2012
C115, C116, C117, C118: 470n; CAPC1608
C129, C130, C131, C132: 470p; CAPC1608
D101, D102, D103, D104: BAT54S; SOT23
HS101: HEATSINK_LGA775; D95263-001
HS102: HEATSINK_LGA115X; E97378-001
Q101, Q103, Q106, Q108, Q116, Q118: BC807; SOT23
Q102, Q104, Q105, Q107, Q111, Q112, Q115, Q117: BC817; SOT23
Q109, Q110, Q113, Q114: SIRC10DP; POWERPAK-SO-8
Q119, Q120: IXTK102N65X2; TO-264P-H-PADUP
R101, R102: 49k3; RESC1608
R103, R104, R105, R106: 5k; RESC1608
R107, R108, R109, R110, R112, R114, R118, R120, R123, R125: 2R; RESC3216
R111, R113, R117, R119: 1k; RESC1608
R115, R116: 100k; RESC1608
R121, R122, R124, R126, R129, R130: 0R01; RESC6332
R127, R128, R131, R132, R133, R134: 2k15; RESC2012
R135, R136, R137, R138: 100R; RESC1608
U101, U102: AD420; SO24W
U103, U104, U105, U106, U107, U108: AD620; SO8
U109, U110: LTC1865L; SO8

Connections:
+3V_1: C133.1, C135.1, D101.2 (C2), D102.2 (C2), U109.8 (VCC); also elsewhere on the board
+3V_2: C134.1, C136.1, D103.2 (C2), D104.2 (C2), U110.8 (VCC); also elsewhere on the board
+5V: C101.1, C102.1, C103.1, C104.1, U101.2 (VLL), U102.2 (VLL); also elsewhere on the board
+12V: C105.1, C106.1, C107.1, C108.1, C109.1, C110.1, C119.1, C120.1, Q115.3 (C), Q117.3 (C), R115.2, R116.2, R117.2, R119.2, U101.23 (VCC), U102.23 (VCC); also elsewhere on the board
+15V: C111.1, C113.1, C115.1, C117.1, C121.1, C122.1, C123.1, C124.1, Q102.3 (C), Q104.3 (C), Q105.3 (C), Q107.3 (C), R103.2, R105.2, U103.7 (+V), U104.7 (+V), U105.7 (+V), U106.7 (+V), U107.7 (+V), U108.7 (+V); also elsewhere on the board
-15V: C112.2, C114.2, C116.2, C118.2, C125.1, C126.1, C127.1, C128.1, Q101.3 (C), Q103.3 (C), Q106.3 (C), Q108.3 (C), R104.1, R106.1, U103.4 (-V), U104.4 (-V), U105.4 (-V), U106.4 (-V), U107.4 (-V), U108.4 (-V); also elsewhere on the board
BPY1G1: Q109.4 (G), R112.2
BYP: R111.1, R113.1; also elsewhere on the board
BYP1: Q117.2 (E), Q118.2 (E), R112.1, R118.1, R128.1
BYP1G2: Q113.4 (G), R118.2
BYP2: Q115.2 (E), Q116.2 (E), R114.1, R120.1, R127.2
BYP2G1: Q110.4 (G), R114.2
BYP2G2: Q114.4 (G), R120.2
CLR_DAC1: U101.6 (CLR); also elsewhere on the board
CLR_DAC2: U102.6 (CLR); also elsewhere on the board
CONV_C1: U109.1 (CONV); also elsewhere on the board
CONV_C2: U110.1 (CONV); also elsewhere on the board
CSEN_H1: Q109.1 (S), Q109.2 (S), Q109.3 (S), Q113.1 (S), Q113.2 (S), Q113.3 (S), R121.2, R123.1, R124.2, R128.2, R129.2, U105.3 (+), U106.2 (-)
CSEN_H2: Q110.1 (S), Q110.2 (S), Q110.3 (S), Q114.1 (S), Q114.2 (S), Q114.3 (S), R122.2, R125.1, R126.2, R127.1, R130.2, U107.3 (+), U108.2 (-)
CSEN_L1: Q109.5 (D), Q109.6 (D), Q109.7 (D), Q109.8 (D), Q113.5 (D), Q113.6 (D), Q113.7 (D), Q113.8 (D), Q119.1 (S), R123.2, U103.5 (REF), U106.3 (+)
CSEN_L2: Q110.5 (D), Q110.6 (D), Q110.7 (D), Q110.8 (D), Q114.5 (D), Q114.6 (D), Q114.7 (D), Q114.8 (D), Q120.1 (S), R125.2, U104.5 (REF), U108.3 (+)
DUT+: Q119.2 (D), Q120.2 (D); also elsewhere on the board
DUT-: R121.1, R122.1, R124.1, R126.1, R129.1, R130.1, U105.2 (-), U107.2 (-); also elsewhere on the board
FLT_DAC: U101.3 (FLT), U102.3 (FLT); also elsewhere on the board
GND: C101.2, C102.2, C103.2, C104.2, C105.2, C106.2, C111.2, C112.1, C113.2, C114.1, C115.2, C116.1, C117.2, C118.1, C119.2, C120.2, C121.2, C122.2, C123.2, C124.2, C125.2, C126.2, C127.2, C128.2, C129.2, C130.2, C131.2, C132.2, C133.2, C134.2, C135.2, C136.2, D101.1 (A1), D102.1 (A1), D103.1 (A1), D104.1 (A1), Q111.2 (E), Q112.2 (E), Q116.3 (C), Q118.3 (C), U101.4 (RS2), U101.5 (RS1), U101.11 (GND), U102.4 (RS2), U102.5 (RS1), U102.11 (GND), U103.2 (-), U104.2 (-), U105.5 (REF), U106.5 (REF), U107.5 (REF), U108.5 (REF), U109.4 (GND), U110.4 (GND); also elsewhere on the board
HIGHC1: C129.1, R135.2, U109.2 (CH0)
HIGHC2: C131.1, R137.2, U110.2 (CH0)
LATCH_DAC: U101.7 (LATCH), U102.7 (LATCH); also elsewhere on the board
LGATE_1: Q119.3 (G), R107.1, R108.2
LGATE_2: Q120.3 (G), R109.1, R110.2
LOWC1: C130.1, R136.2, U109.3 (CH1)
LOWC2: C132.1, R138.2, U110.3 (CH1)
MISO: U109.6 (SDO), U110.6 (SDO); also elsewhere on the board
MOSI: U101.9 (SDI), U109.5 (SDI), U110.5 (SDI); also elsewhere on the board
unnamed: Q101.2 (E), Q105.1 (B), R103.1
unnamed: R101.2, U103.1 (RG)
unnamed: C107.2, U101.21 (C2)
unnamed: C109.2, U101.20 (C1)
unnamed: Q112.3 (C), Q117.1 (B), Q118.1 (B), R119.1
unnamed: R101.1, U103.8 (RG)
unnamed: D101.3 (C1A2), R135.1, U105.6 (OUT)
unnamed: Q112.1 (B), R113.2, R116.1
unnamed: U101.17 (VOUT), U103.3 (+)
unnamed: Q106.2 (E), R108.1
unnamed: Q103.2 (E), Q107.1 (B), R105.1
unnamed: Q105.2 (E), R107.2
unnamed: Q108.2 (E), R110.1
unnamed: Q107.2 (E), R109.2
unnamed: D102.3 (C1A2), R136.1, U106.6 (OUT)
unnamed: Q111.3 (C), Q115.1 (B), Q116.1 (B), R117.1
unnamed: Q111.1 (B), R111.2, R115.1
unnamed: C108.2, U102.21 (C2)
unnamed: C110.2, U102.20 (C1)
unnamed: Q103.1 (B), Q104.1 (B), U104.6 (OUT)
unnamed: Q104.2 (E), Q108.1 (B), R106.2
unnamed: R102.2, U104.1 (RG)
unnamed: R102.1, U104.8 (RG)
unnamed: U102.17 (VOUT), U104.3 (+)
unnamed: D103.3 (C1A2), R137.1, U107.6 (OUT)
unnamed: D104.3 (C1A2), R138.1, U108.6 (OUT)
unnamed: Q101.1 (B), Q102.1 (B), U103.6 (OUT)
unnamed: Q102.2 (E), Q106.1 (B), R104.2
RG1_L1: R133.2, U107.1 (RG)
RG1_L2: R134.2, U108.1 (RG)
RG1_L3: R131.2, U105.1 (RG)
RG1_L4: R132.2, U106.1 (RG)
RG2_L1: R133.1, U107.8 (RG)
RG2_L2: R134.1, U108.8 (RG)
RG2_L3: R131.1, U105.8 (RG)
RG2_L4: R132.1, U106.8 (RG)
SCK: U101.8 (SCK), U102.8 (SCK), U109.7 (SCK), U110.7 (SCK); also elsewhere on the board
SDO_DAC1: U101.10 (SDO), U102.9 (SDI)
SDO_DAC2: U102.10 (SDO)
VREF1: U101.14 (REF_OUT), U101.15 (REF_IN); also elsewhere on the board
VREF2: U102.14 (REF_OUT), U102.15 (REF_IN); also elsewhere on the board

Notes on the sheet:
Gate Drive 1
Gate drive 2

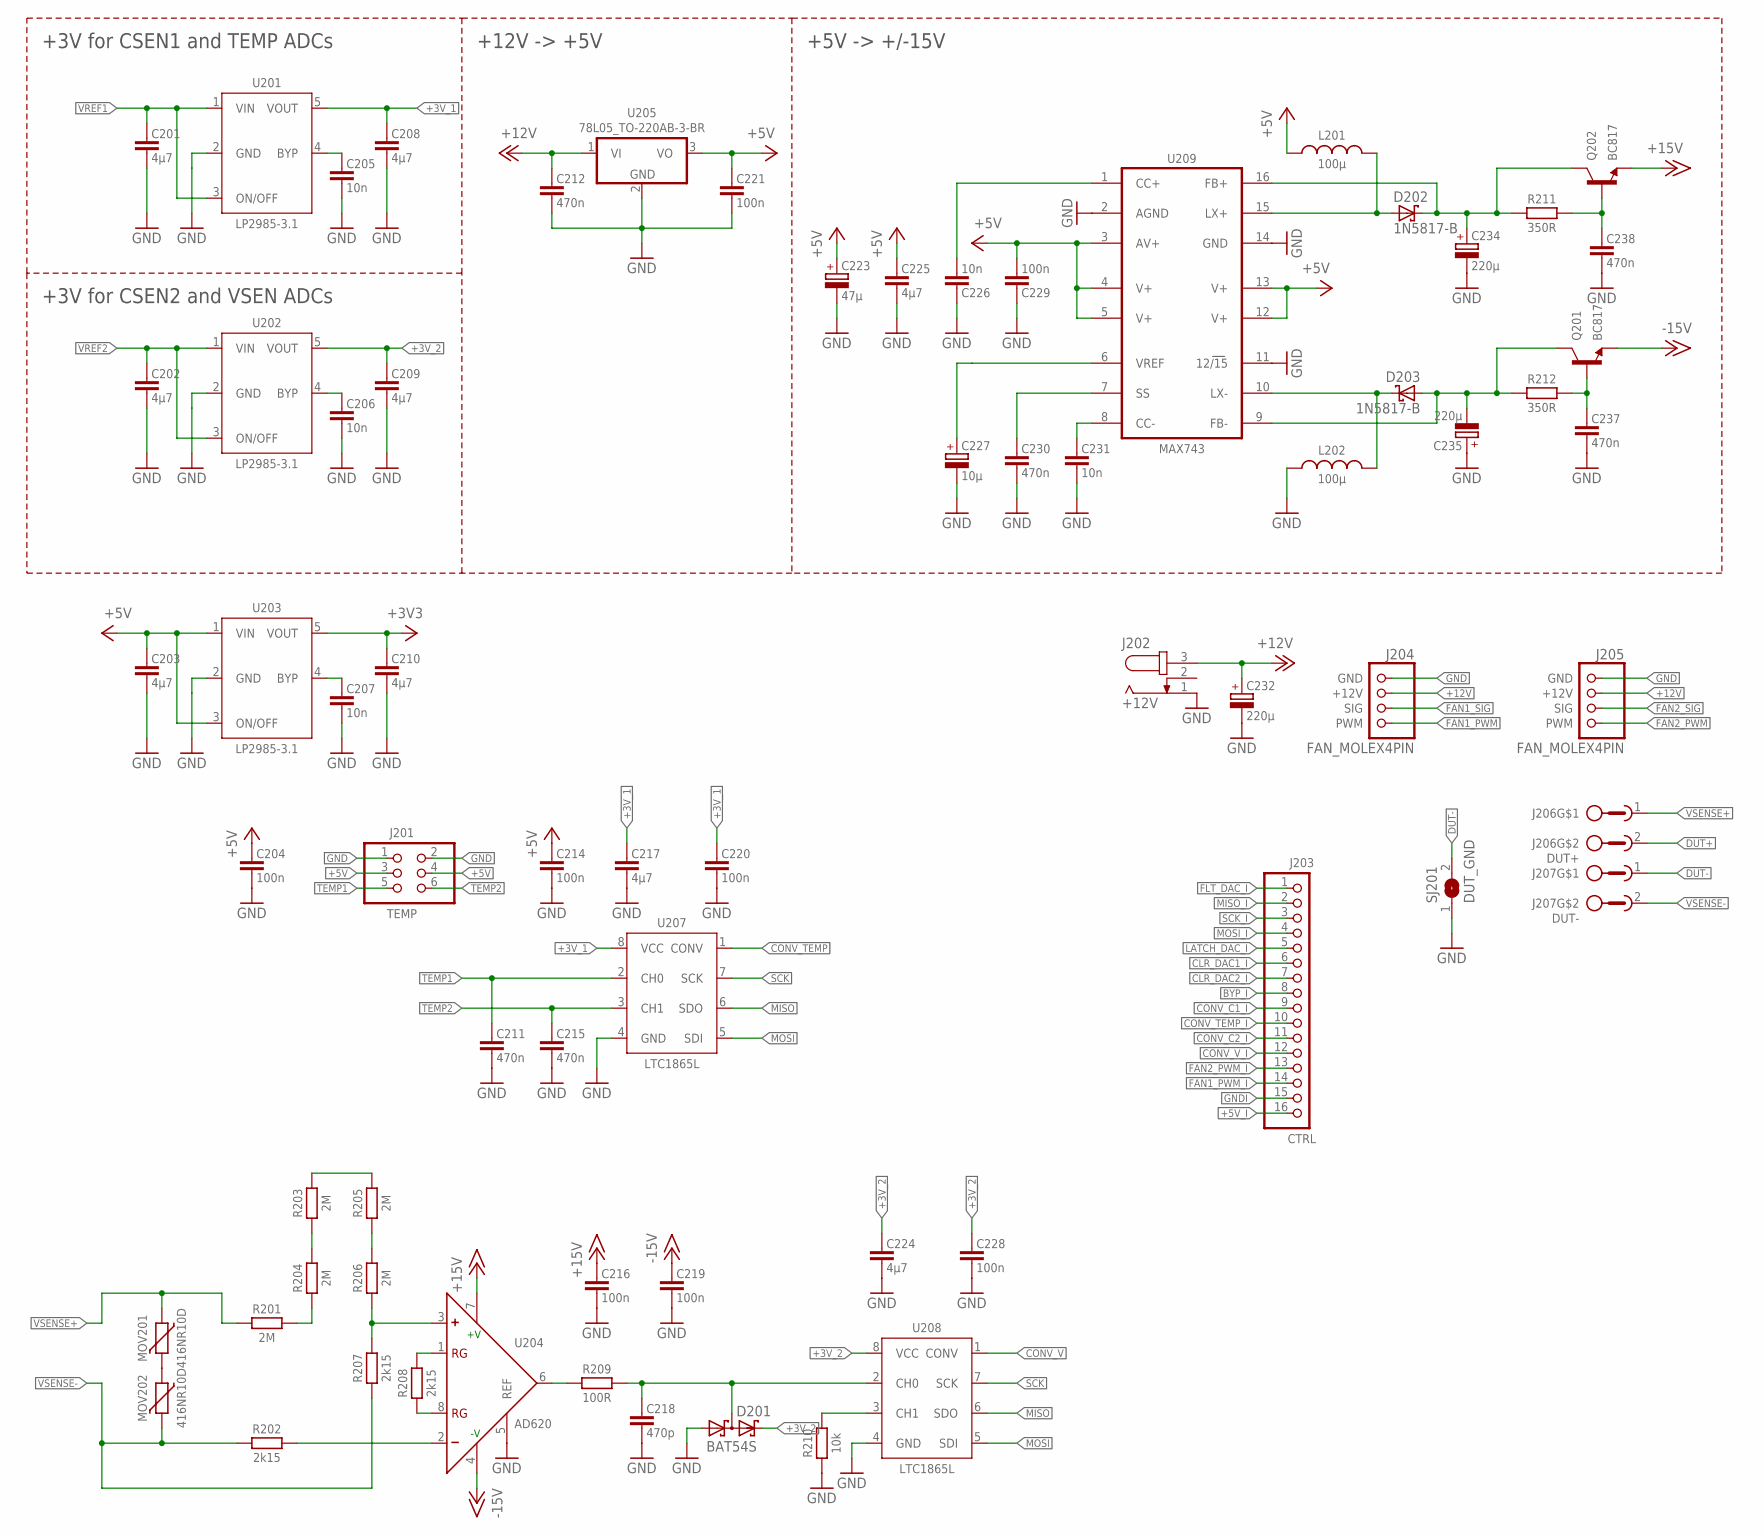
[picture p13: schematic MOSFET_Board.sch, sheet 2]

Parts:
C201, C202, C203, C208, C209, C210, C217, C224, C225: 4µ7; CAPC3216
C204, C214, C216, C219, C220, C221, C228, C229: 100n; CAPC1608
C205, C206, C207, C226, C231: 10n; CAPC2012
C211, C212, C215, C230, C237, C238: 470n; CAPC1608
C218: 470p; CAPC1608
C223: 47µ; CAPCP7343
C227: 10µ; CAPCP6032
C232, C234, C235: 220µ; CAPPRD500W60D1000H
D201: BAT54S; SOT23
D202, D203: 1N5817-B; DO41-7.6
J201: TEMP; HEAD_MALE_2X3
J202: +12V; SPC4078
J203: CTRL; HEAD_MALE_1X16
J204, J205: FAN_MOLEX4PIN; MOLEX_47053-1000
J206: DUT+; AMPHENOL-12-762_2
J207: DUT-; AMPHENOL-12-762_2
L201, L202: 100µ; MSS1260
MOV201, MOV202: 416NR10D; DISK_9.5MM
Q201, Q202: BC817; SOT23
R201, R203, R204, R205, R206: 2M; RESC3216
R202, R207, R208: 2k15; RESC2012
R209: 100R; RESC1608
R210: 10k; RESC1608
R211, R212: 350R; RESC1608
SJ201: DUT_GND; SJW
U201, U202, U203: LP2985-3.1; SOT23-5L
U204: AD620; SO8
U205: 78L05_TO-220AB-3-BR; TO-220AB-3-BR
U207, U208: LTC1865L; SO8
U209: MAX743; SO16W

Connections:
+3V3: C210.1, U203.5 (VOUT); also elsewhere on the board
+3V_1: C208.1, C217.1, C220.1, U201.5 (VOUT), U207.8 (VCC); also elsewhere on the board
+3V_2: C209.1, C224.1, C228.1, D201.2 (C2), U202.5 (VOUT), U208.8 (VCC); also elsewhere on the board
+5V: C203.1, C204.1, C214.1, C221.1, C223.+, C225.1, C229.2, J201.3, J201.4, L201.1, U203.1 (VIN), U203.3 (ON/OFF), U205.3 (VO), U209.3 (AV+), U209.4 (V+), U209.5 (V+), U209.12 (V+), U209.13 (V+); also elsewhere on the board
+5V_I: J203.16; also elsewhere on the board
+12V: C212.1, C232.+, J202.3, J204.2 (+12V), J205.2 (+12V), U205.1 (VI); also elsewhere on the board
+15V: C216.1, Q202.2 (E), U204.7 (+V); also elsewhere on the board
-15V: C219.1, Q201.2 (E), U204.4 (-V); also elsewhere on the board
BYP_I: J203.8; also elsewhere on the board
CLR_DAC1_I: J203.6; also elsewhere on the board
CLR_DAC2_I: J203.7; also elsewhere on the board
CONV_C1_I: J203.9; also elsewhere on the board
CONV_C2_I: J203.11; also elsewhere on the board
CONV_TEMP: U207.1 (CONV); also elsewhere on the board
CONV_TEMP_I: J203.10; also elsewhere on the board
CONV_V: U208.1 (CONV); also elsewhere on the board
CONV_V_I: J203.12; also elsewhere on the board
DUT+: J206.2; also elsewhere on the board
DUT-: J207.1, SJ201.2; also elsewhere on the board
FAN1_PWM: J204.4 (PWM); also elsewhere on the board
FAN1_PWM_I: J203.14; also elsewhere on the board
FAN1_SIG: J204.3 (SIG)
FAN2_PWM: J205.4 (PWM); also elsewhere on the board
FAN2_PWM_I: J203.13; also elsewhere on the board
FAN2_SIG: J205.3 (SIG)
FLT_DAC_I: J203.1; also elsewhere on the board
GND: C201.2, C202.2, C203.2, C204.2, C205.2, C206.2, C207.2, C208.2, C209.2, C210.2, C211.2, C212.2, C214.2, C215.2, C216.2, C217.2, C218.2, C219.2, C220.2, C221.2, C223.-, C224.2, C225.2, C226.1, C227.-, C228.2, C229.1, C230.2, C231.2, C232.-, C234.-, C235.+, C237.2, C238.2, D201.1 (A1), J201.1, J201.2, J202.1, J204.1 (GND), J205.1 (GND), L202.2, R210.1, SJ201.1, U201.2 (GND), U202.2 (GND), U203.2 (GND), U204.5 (REF), U205.2 (GND), U207.4 (GND), U208.4 (GND), U209.2 (AGND), U209.11 (12/15), U209.14 (GND); also elsewhere on the board
GNDI: J203.15; also elsewhere on the board
LATCH_DAC_I: J203.5; also elsewhere on the board
MISO: U207.6 (SDO), U208.6 (SDO); also elsewhere on the board
MISO_I: J203.2; also elsewhere on the board
MOSI: U207.5 (SDI), U208.5 (SDI); also elsewhere on the board
MOSI_I: J203.4; also elsewhere on the board
unnamed: C205.1, U201.4 (BYP)
unnamed: R209.1, U204.6 (OUT)
unnamed: R205.1, R206.2
unnamed: R203.2, R205.2
unnamed: R203.1, R204.2
unnamed: MOV201.2, MOV202.1
unnamed: R206.1, R207.2, U204.3 (+)
unnamed: C218.1, D201.3 (C1A2), R209.2, U208.2 (CH0)
unnamed: C234.+, D202.C, Q202.3 (C), R211.1, U209.16 (FB+)
unnamed: R201.2, R204.1
unnamed: C231.1, U209.8 (CC-)
unnamed: C230.1, U209.7 (SS)
unnamed: R202.2, U204.2 (-)
unnamed: C226.2, U209.1 (CC+)
unnamed: D202.A, L201.2, U209.15 (LX+)
unnamed: D203.C, L202.1, U209.10 (LX-)
unnamed: R210.2, U208.3 (CH1)
unnamed: C206.1, U202.4 (BYP)
unnamed: C238.1, Q202.1 (B), R211.2
unnamed: C235.-, D203.A, Q201.3 (C), R212.1, U209.9 (FB-)
unnamed: C237.1, Q201.1 (B), R212.2
unnamed: C207.1, U203.4 (BYP)
RG1_H6: R208.2, U204.1 (RG)
RG2_H6: R208.1, U204.8 (RG)
SCK: U207.7 (SCK), U208.7 (SCK); also elsewhere on the board
SCK_I: J203.3; also elsewhere on the board
TEMP1: C211.1, J201.5, U207.2 (CH0)
TEMP2: C215.1, J201.6, U207.3 (CH1)
VREF1: C201.1, U201.1 (VIN), U201.3 (ON/OFF); also elsewhere on the board
VREF2: C202.1, U202.1 (VIN), U202.3 (ON/OFF); also elsewhere on the board
VREF_MAX743: C227.+, U209.6 (VREF)
VSENSE+: J206.1, MOV201.1, R201.1
VSENSE-: J207.2, MOV202.2, R202.1, R207.1

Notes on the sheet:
+3V for CSEN1 and TEMP ADCs
+3V for CSEN2 and VSEN ADCs
+5V -> +/-15V
+12V -> +5V

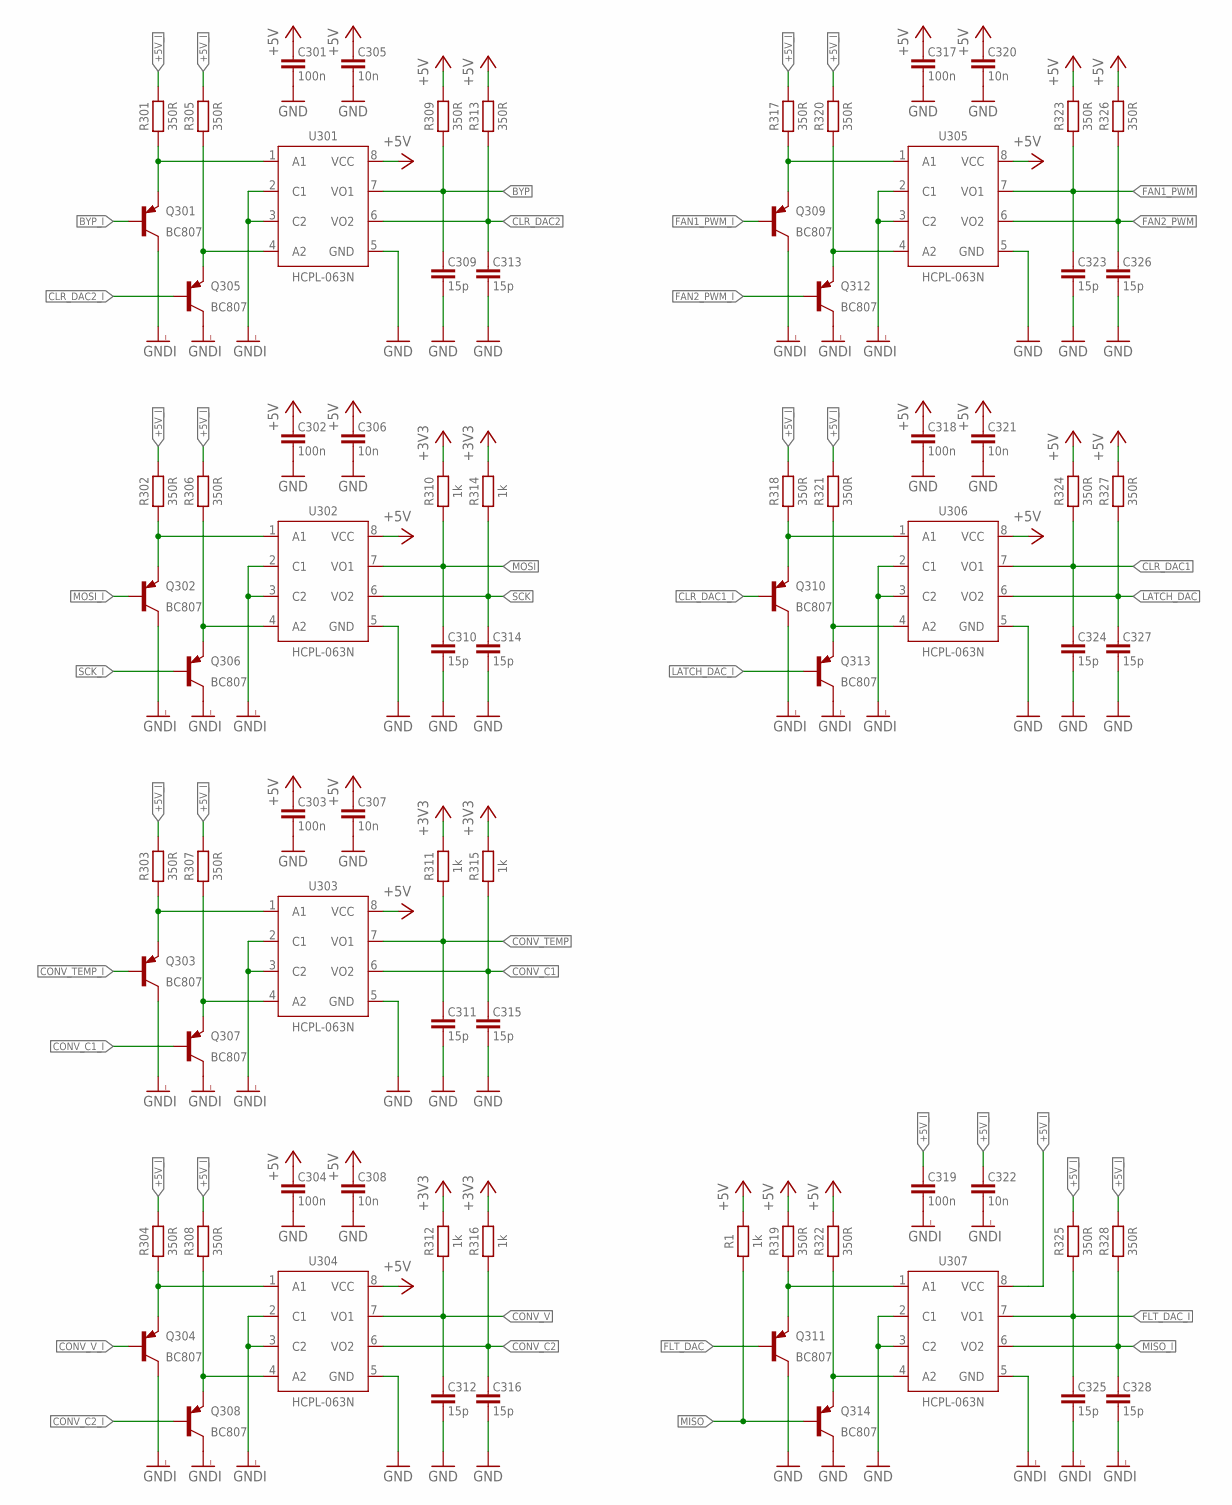
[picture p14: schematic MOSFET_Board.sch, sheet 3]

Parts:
C301, C302, C303, C304, C317, C318, C319: 100n; CAPC1608
C305, C306, C307, C308, C320, C321, C322: 10n; CAPC1608
C309, C310, C311, C312, C313, C314, C315, C316, C323, C324, C325, C326, C327, C328: 15p; CAPC1608
Q301, Q302, Q303, Q304, Q305, Q306, Q307, Q308, Q309, Q310, Q311, Q312, Q313, Q314: BC807; SOT23
R1, R310, R311, R312, R314, R315, R316: 1k; RESC1608
R301, R302, R303, R304, R305, R306, R307, R308, R309, R313, R317, R318, R319, R320, R321, R322, R323, R324, R325, R326, R327, R328: 350R; RESC1608
U301, U302, U303, U304, U305, U306, U307: HCPL-063N; SO8

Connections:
+3V3: R310.2, R311.2, R312.2, R314.2, R315.2, R316.2; also elsewhere on the board
+5V: C301.1, C302.1, C303.1, C304.1, C305.1, C306.1, C307.1, C308.1, C317.1, C318.1, C320.1, C321.1, R1.2, R309.2, R313.2, R319.2, R322.2, R323.2, R324.2, R326.2, R327.2, U301.8 (VCC), U302.8 (VCC), U303.8 (VCC), U304.8 (VCC), U305.8 (VCC), U306.8 (VCC); also elsewhere on the board
+5V_I: C319.1, C322.1, R301.2, R302.2, R303.2, R304.2, R305.2, R306.2, R307.2, R308.2, R317.2, R318.2, R320.2, R321.2, R325.2, R328.2, U307.8 (VCC); also elsewhere on the board
BYP: C309.1, R309.1, U301.7 (VO1); also elsewhere on the board
BYP_I: Q301.1 (B); also elsewhere on the board
CLR_DAC1: C324.1, R324.1, U306.7 (VO1); also elsewhere on the board
CLR_DAC1_I: Q310.1 (B); also elsewhere on the board
CLR_DAC2: C313.1, R313.1, U301.6 (VO2); also elsewhere on the board
CLR_DAC2_I: Q305.1 (B); also elsewhere on the board
CONV_C1: C315.1, R315.1, U303.6 (VO2); also elsewhere on the board
CONV_C1_I: Q307.1 (B); also elsewhere on the board
CONV_C2: C316.1, R316.1, U304.6 (VO2); also elsewhere on the board
CONV_C2_I: Q308.1 (B); also elsewhere on the board
CONV_TEMP: C311.1, R311.1, U303.7 (VO1); also elsewhere on the board
CONV_TEMP_I: Q303.1 (B); also elsewhere on the board
CONV_V: C312.1, R312.1, U304.7 (VO1); also elsewhere on the board
CONV_V_I: Q304.1 (B); also elsewhere on the board
FAN1_PWM: C323.1, R323.1, U305.7 (VO1); also elsewhere on the board
FAN1_PWM_I: Q309.1 (B); also elsewhere on the board
FAN2_PWM: C326.1, R326.1, U305.6 (VO2); also elsewhere on the board
FAN2_PWM_I: Q312.1 (B); also elsewhere on the board
FLT_DAC: Q311.1 (B); also elsewhere on the board
FLT_DAC_I: C325.1, R325.1, U307.7 (VO1); also elsewhere on the board
GND: C301.2, C302.2, C303.2, C304.2, C305.2, C306.2, C307.2, C308.2, C309.2, C310.2, C311.2, C312.2, C313.2, C314.2, C315.2, C316.2, C317.2, C318.2, C320.2, C321.2, C323.2, C324.2, C326.2, C327.2, Q311.3 (C), Q314.3 (C), U301.5 (GND), U302.5 (GND), U303.5 (GND), U304.5 (GND), U305.5 (GND), U306.5 (GND), U307.2 (C1), U307.3 (C2); also elsewhere on the board
GNDI: C319.2, C322.2, C325.2, C328.2, Q301.3 (C), Q302.3 (C), Q303.3 (C), Q304.3 (C), Q305.3 (C), Q306.3 (C), Q307.3 (C), Q308.3 (C), Q309.3 (C), Q310.3 (C), Q312.3 (C), Q313.3 (C), U301.2 (C1), U301.3 (C2), U302.2 (C1), U302.3 (C2), U303.2 (C1), U303.3 (C2), U304.2 (C1), U304.3 (C2), U305.2 (C1), U305.3 (C2), U306.2 (C1), U306.3 (C2), U307.5 (GND); also elsewhere on the board
LATCH_DAC: C327.1, R327.1, U306.6 (VO2); also elsewhere on the board
LATCH_DAC_I: Q313.1 (B); also elsewhere on the board
MISO: Q314.1 (B), R1.1; also elsewhere on the board
MISO_I: C328.1, R328.1, U307.6 (VO2); also elsewhere on the board
MOSI: C310.1, R310.1, U302.7 (VO1); also elsewhere on the board
MOSI_I: Q302.1 (B); also elsewhere on the board
unnamed: Q311.2 (E), R319.1, U307.1 (A1)
unnamed: Q314.2 (E), R322.1, U307.4 (A2)
unnamed: Q304.2 (E), R304.1, U304.1 (A1)
unnamed: Q308.2 (E), R308.1, U304.4 (A2)
unnamed: Q302.2 (E), R302.1, U302.1 (A1)
unnamed: Q306.2 (E), R306.1, U302.4 (A2)
unnamed: Q309.2 (E), R317.1, U305.1 (A1)
unnamed: Q312.2 (E), R320.1, U305.4 (A2)
unnamed: Q301.2 (E), R301.1, U301.1 (A1)
unnamed: Q305.2 (E), R305.1, U301.4 (A2)
unnamed: Q310.2 (E), R318.1, U306.1 (A1)
unnamed: Q313.2 (E), R321.1, U306.4 (A2)
unnamed: Q303.2 (E), R303.1, U303.1 (A1)
unnamed: Q307.2 (E), R307.1, U303.4 (A2)
SCK: C314.1, R314.1, U302.6 (VO2); also elsewhere on the board
SCK_I: Q306.1 (B); also elsewhere on the board

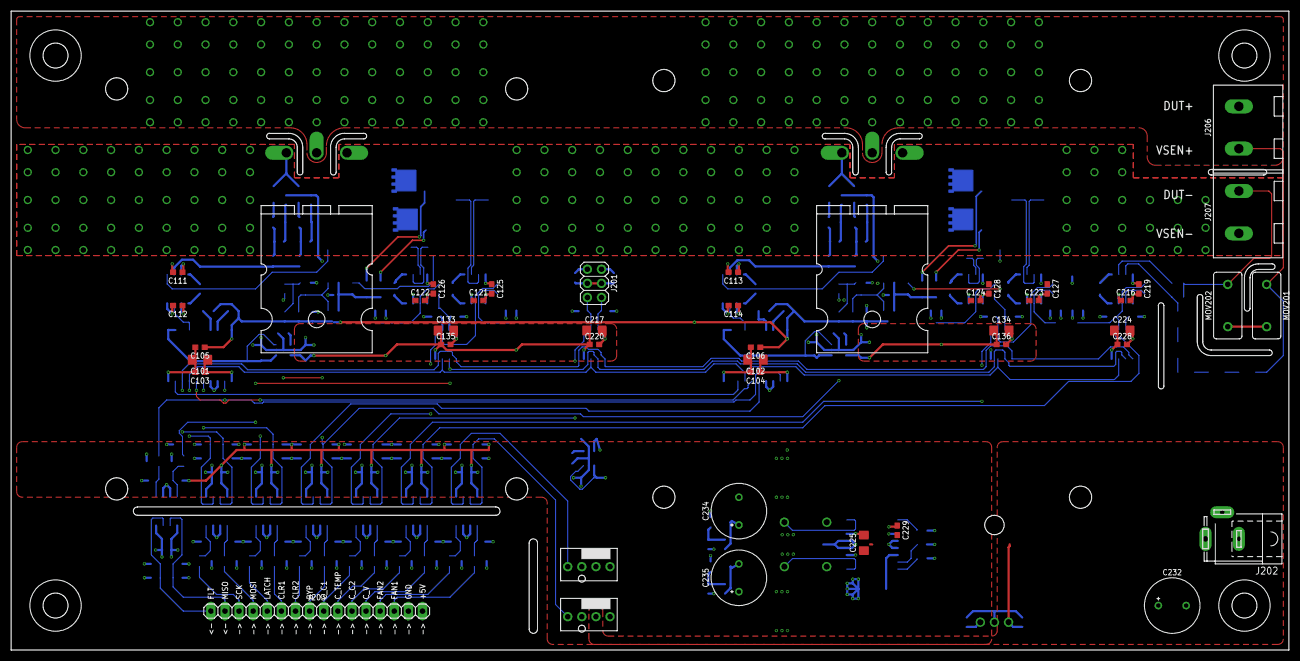
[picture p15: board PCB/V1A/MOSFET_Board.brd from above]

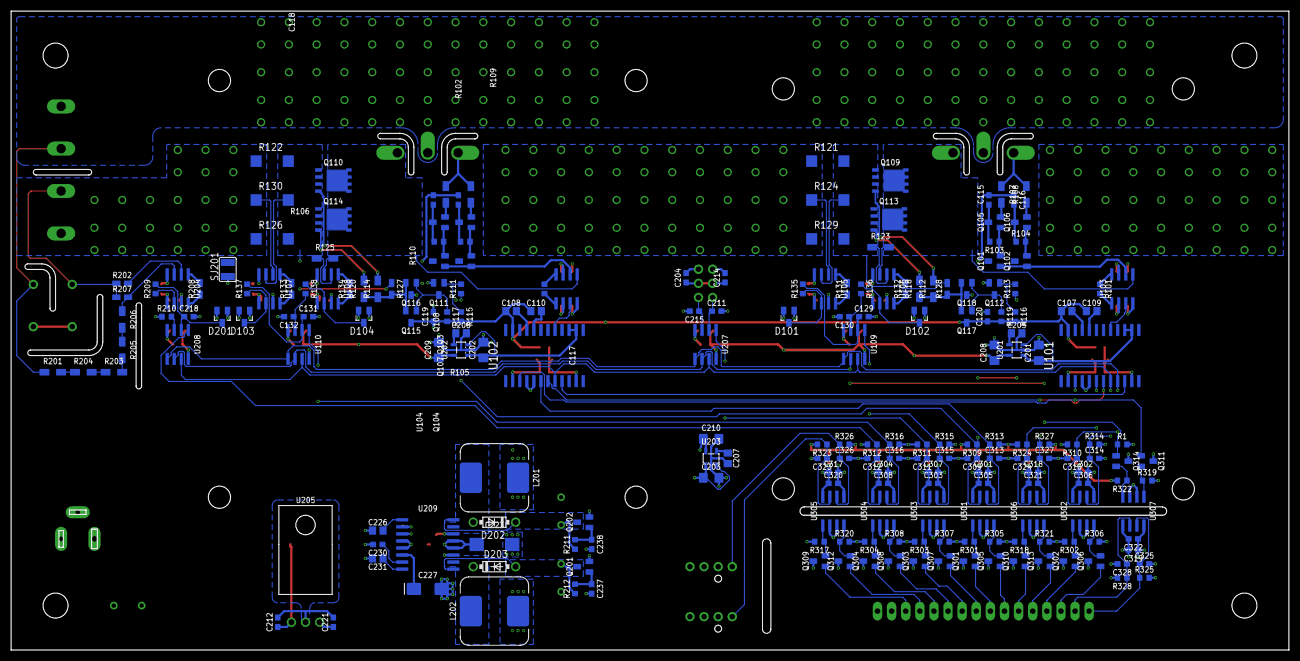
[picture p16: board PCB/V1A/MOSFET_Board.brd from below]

Board: 4 copper layers, 230.0 x 115.0 mm, 263 parts (213 on the bottom side), 138 nets.

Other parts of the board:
U$6, U$7, U$8, U$9: M4

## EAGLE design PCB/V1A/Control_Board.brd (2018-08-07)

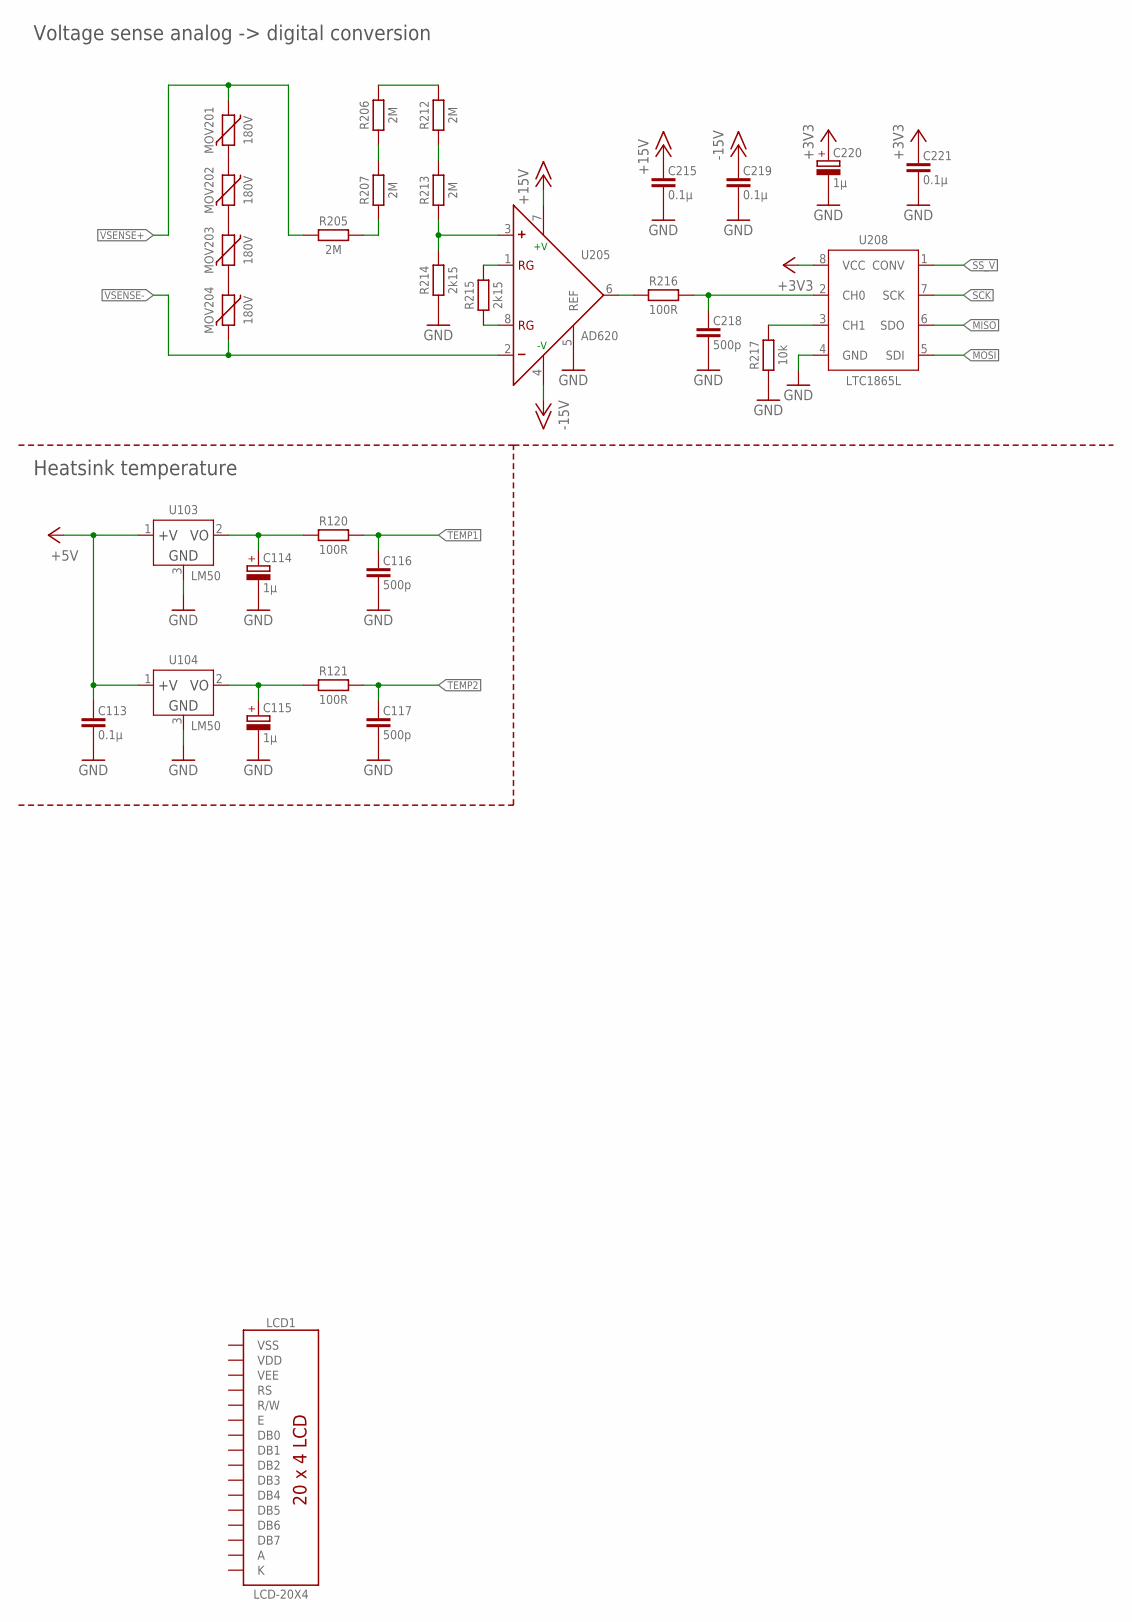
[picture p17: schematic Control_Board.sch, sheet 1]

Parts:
C113, C215, C219, C221: 0.1µ; C3216
C114, C115, C220: 1µ; CT3216
C116, C117, C218: 500p; C1608
LCD1: LCD-20X4; 4X20_LED
MOV201, MOV202, MOV203, MOV204: 180V; R3225W
R120, R121, R216: 100R; R2012W
R205, R206, R207, R212, R213: 2M; R3216W
R214, R215: 2k15; R2012W
R217: 10k; R1608
U103, U104: LM50; SOT23W
U205: AD620; SO8
U208: LTC1865L; SO8

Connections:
+3V3: C220.+, C221.1, U208.8 (VCC); also elsewhere on the board
+5V: C113.1, U103.1 (+V), U104.1 (+V); also elsewhere on the board
+15V: C215.1, U205.7 (+V); also elsewhere on the board
-15V: C219.1, U205.4 (-V); also elsewhere on the board
A: LCD1.15 (A)
GND: C113.2, C114.-, C115.-, C116.2, C117.2, C215.2, C218.2, C219.2, C220.-, C221.2, R214.1, R217.1, U103.3 (GND), U104.3 (GND), U205.5 (REF), U208.4 (GND); also elsewhere on the board
K: LCD1.16 (K)
MISO: U208.6 (SDO)
MOSI: U208.5 (SDI)
unnamed: MOV201.2, MOV202.1
unnamed: MOV202.2, MOV203.1
unnamed: R212.1, R213.2
unnamed: R206.2, R212.2
unnamed: R206.1, R207.2
unnamed: R205.2, R207.1
unnamed: R213.1, R214.2, U205.3 (+)
unnamed: C218.1, R216.2, U208.2 (CH0)
unnamed: R216.1, U205.6 (OUT)
unnamed: MOV203.2, MOV204.1
unnamed: R217.2, U208.3 (CH1)
RG1_H6: R215.2, U205.1 (RG)
RG2_H6: R215.1, U205.8 (RG)
SCK: U208.7 (SCK)
SS_V: U208.1 (CONV)
T1_OUT: C114.+, R120.1, U103.2 (VO)
T2_OUT: C115.+, R121.1, U104.2 (VO)
TEMP1: C116.1, R120.2
TEMP2: C117.1, R121.2
VDD: LCD1.2 (VDD)
VEE: LCD1.3 (VEE)
VSENSE+: MOV201.1, R205.1
VSENSE-: MOV204.2, U205.2 (-)
VSS: LCD1.1 (VSS)

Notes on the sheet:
Voltage sense analog -> digital conversion
Heatsink temperature

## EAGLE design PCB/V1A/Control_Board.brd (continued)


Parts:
C301: 0.33µ; C3216
C303, C305: 0.1µ; C3216
C304: 1µ; C3216
C306: 1µ; CT3216
C307, C309, C310: 10n; C3216
C308: 10µ; CT6032
C311: 2µ2; C3216
C312: 22µ; CT6032
C313, C314: 220µ; E3,5-10
D301, D302: 1N5817-B; DO41-7.6
IC301: 7805T; TO220H
J301: JACK-PLUG0; SPC4077
L301, L302: 100µ; SRN1060
SV1, SV3: FE07-2W
U301: LP2985-3.1; SOT23-5L
U302: MAX743; SO16W

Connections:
+3V3: C311.1, U301.5 (VOUT); also elsewhere on the board
+5V: C303.1, C304.1, C305.2, C312.+, IC301.3 (VO), L302.1, U301.1 (VIN), U301.3 (ON/OFF), U302.3 (AV+), U302.4 (V+), U302.5 (V+), U302.12 (V+), U302.13 (V+); also elsewhere on the board
+12V: C301.1, IC301.1 (VI), J301.3
+15V: C313.+, D301.C, U302.16 (FB+); also elsewhere on the board
-15V: C314.-, D302.A, U302.9 (FB-); also elsewhere on the board
GND: C301.2, C303.2, C304.2, C305.1, C306.-, C307.1, C308.-, C309.2, C310.2, C311.2, C312.-, C313.-, C314.+, IC301.2 (GND), J301.1, J301.2, L301.2, U301.2 (GND), U302.2 (AGND), U302.11 (12/15), U302.14 (GND); also elsewhere on the board
unnamed: C310.1, U301.4 (BYP)
unnamed: C309.1, U302.8 (CC-)
unnamed: C306.+, U302.7 (SS)
unnamed: C307.2, U302.1 (CC+)
unnamed: D301.A, L302.2, U302.15 (LX+)
unnamed: D302.C, L301.1, U302.10 (LX-)
VREF2: C308.+, U302.6 (VREF)

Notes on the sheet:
Voltage regulation

Board: 2 copper layers, 53 parts (0 on the bottom side), 32 nets, no tracks yet.

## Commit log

2018-05-10 Added buffer amplifiers
    [Electronic_Load_V1A.sch]
2018-05-12 Updated DAC buffer amps & datasheets
    Changed the positive supply of DAC buffer op amps from +5V to +12V, added input offset trimming and set their gain to 2 (1.98). This was done in order to achieve maximum current at low voltages by in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
    [Electronic_Load_V1A.sch, MOSFET comparison.xlsx]
2018-05-16 Added MOSFET models, updated info
    [Electronic_Load_V1A.sch, Heatsink mount v10.step, MOSFET comparison.xlsx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]
2018-05-18 Added voltage regulators
    [Electronic_Load_V1A.sch]
2018-05-18 Changed measurement opamps to OPA77
    [Electronic_Load_V1A.sch, Part list.xlsx]
2018-05-20 Created board layout, added info
    [Electronic_Load_V1A.brd, Electronic_Load_V1A.sch, MOSFET comparison.xlsx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]
2018-05-21 Board layout work
    [Electronic_Load_V1A.brd, Electronic_Load_V1A.sch]
2018-05-22 Board layout work
    PCB is 100x100mm 2 layer 2oz. MOSFETs mounted between a plate and heatsinks, control board mounted under the plate. DUT+ connected directly from binding post to drains, gates and sources connected to PCB with wires.
    [20X4LCD JHD204A.STEP, Electronic_Load_V1A.brd, Electronic_Load_V1A.sch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]
2018-05-23 Added temp sensors
    [Electronic_Load_V1A.brd, Electronic_Load_V1A.sch, Part list.xlsx]
2018-05-23 Changed packages, board layout
    Changed component packages and values to the ones that are available. Moved the heatsink mount back to the PCB,
    [Electronic_Load_V1A.brd, Electronic_Load_V1A.sch, Part list.xlsx]
2018-05-24 Updated part list
    [Electronic_Load_V1A.brd, Electronic_Load_V1A.sch, Part list.xlsx]
2018-05-25 Changed OPA77 to AD620
    [Electronic_Load_V1A.brd, Electronic_Load_V1A.sch, Part list.xlsx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]
2018-05-25 Added optocouplers
    [Electronic_Load_V1A.brd, Electronic_Load_V1A.sch, Ranges.xlsx]
2018-05-25 Removed board layout, updated schematic layout
    [Electronic_Load_V1A.sch]
2018-05-27 Schematic & layout work; added block diagram
    [Electronic_Load_V1A.brd, Electronic_Load_V1A.sch]
2018-05-27 Added heatsink models, ADC/DAC layout
    [Electronic_Load_V1A.brd, Electronic_Load_V1A.sch, Heatsink mount v10.step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]
2018-05-28 ADC/DAC board layout
    [Electronic_Load_V1A.brd, Electronic_Load_V1A.sch]
2018-05-29 Board layout
    [Electronic_Load_V1A.brd]
2018-05-31 Board layout, added remote sense input protection
    [Electronic_Load_V1A.brd, Electronic_Load_V1A.sch]
2018-06-04 Added display layout
    [Electronic_Load_V1A.brd]
2018-06-04 Updated schematic
    [Electronic_Load_V1A.brd, Electronic_Load_V1A.sch]
2018-06-10 Removed external parts from PCB, added Front Panel PCB
    [Electronic_Load_V1A.brd, Electronic_Load_V1A.sch, Front_Panel_V1A.brd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]
2018-07-27 Added Gate driver simulation
    [Electronic_Load_V1A.brd, Electronic_Load_V1A.sch]
2018-08-03 Simulation, layout & info - V4A
    [Book1.xlsx, Control_Board.brd, Control_Board.sch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]
2018-08-07 Added optoisolation to MOSFET board
    [Control_Board.brd, MOSFET_Board.brd, MOSFET_Board.sch]
2018-08-11 Changed to single board design
    [MOSFET_Board.brd, MOSFET_Board.sch, Ranges.xlsx]
2018-08-17 PCB layout
    [MOSFET_Board.brd, MOSFET_Board.sch, Ranges.xlsx]
2018-08-21 Added block diagram
    [MOSFET_Board.brd, MOSFET_Board.sch, Ranges.xlsx]
2018-08-22 PCB layout, cleaned part list
    [MOSFET_Board.brd, MOSFET_Board.sch, Part list.xlsx]
2018-08-23 Removed abandoned PCB attempts
    [Control_Board.brd, Control_Board.sch, Electronic_Load_AD_V2A.brd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]
2018-08-23 Finalizing components & placement
    [MOSFET_Board.brd, MOSFET_Board.sch, Part list.xlsx]
2018-08-24 Cleaned DOCS
    [Book1.xlsx, MOSFET comparison.xlsx, MOSFET_Board.brd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]
2018-08-28 PCB layout & simulation
    Added capacitance multiplier to +/-15V rails
    [MOSFET_Board.brd, MOSFET_Board.sch]
2018-08-30 Finished first pass routing/layout
    [MOSFET_Board.brd, MOSFET_Board.sch]
2018-09-07 PCB layout
    Added some copper pours.
    [MOSFET_Board.brd, MOSFET_Board.sch]
2018-09-28 Added power amp for load MOSFET gate
    [MOSFET_Board.brd, MOSFET_Board.sch]
2018-09-29 Gate driver simulations
2018-10-04 Changed load path layout
    [MOSFET_Board.brd, MOSFET_Board.sch]
2018-10-05 Cleaned up schematic; PCB layout
    [MOSFET_Board.brd, MOSFET_Board.sch]
2018-10-08 Schematic layout
    [MOSFET_Board.brd, MOSFET_Board.sch]
2019-03-31 Added V2A board/schematic
    [MOSFET_Board.brd, MOSFET_Board.sch, Power_thermal.xlsx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]
2019-04-06 V2A fully routed
    [MOSFET_Board.brd, MOSFET_Board.sch, Power_thermal.xlsx]
